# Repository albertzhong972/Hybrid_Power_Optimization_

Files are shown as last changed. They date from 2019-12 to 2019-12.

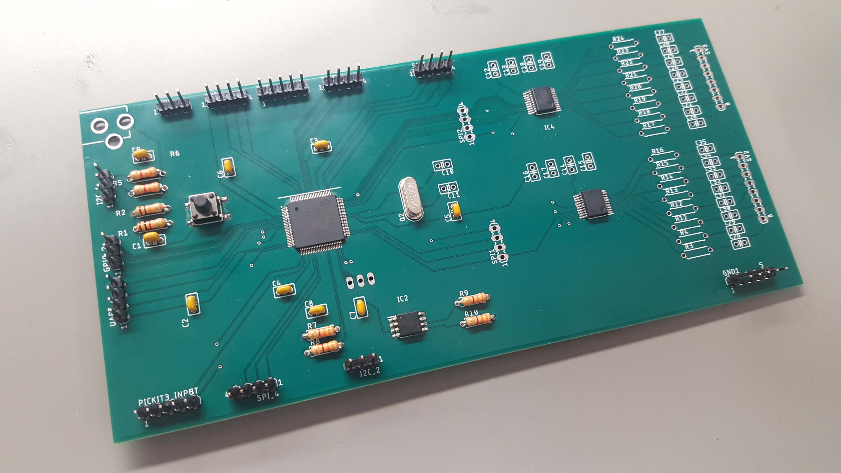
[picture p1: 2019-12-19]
Albert's Files/20191014_151341.jpg

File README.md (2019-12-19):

# Hybrid-Power-Optimization
ECEN 404 Senior Design - Hybrid Power Optimization

Project Description:
We are combining DC power from a solar panel with AC power from the grid to provide power to a load. We are using a PIC32MK microcontroller in this project.

There are four subsystems:
  -Power (Antonio)
  -PCB (Albert)
  -Software/Firmware (Eduardo)
  -Feedback (Heraclio)

  You can find our individual work as well as our progress reports in our own folders.

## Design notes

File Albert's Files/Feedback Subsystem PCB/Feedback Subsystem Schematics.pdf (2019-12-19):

AC Voltage Read Circuit
Schematic

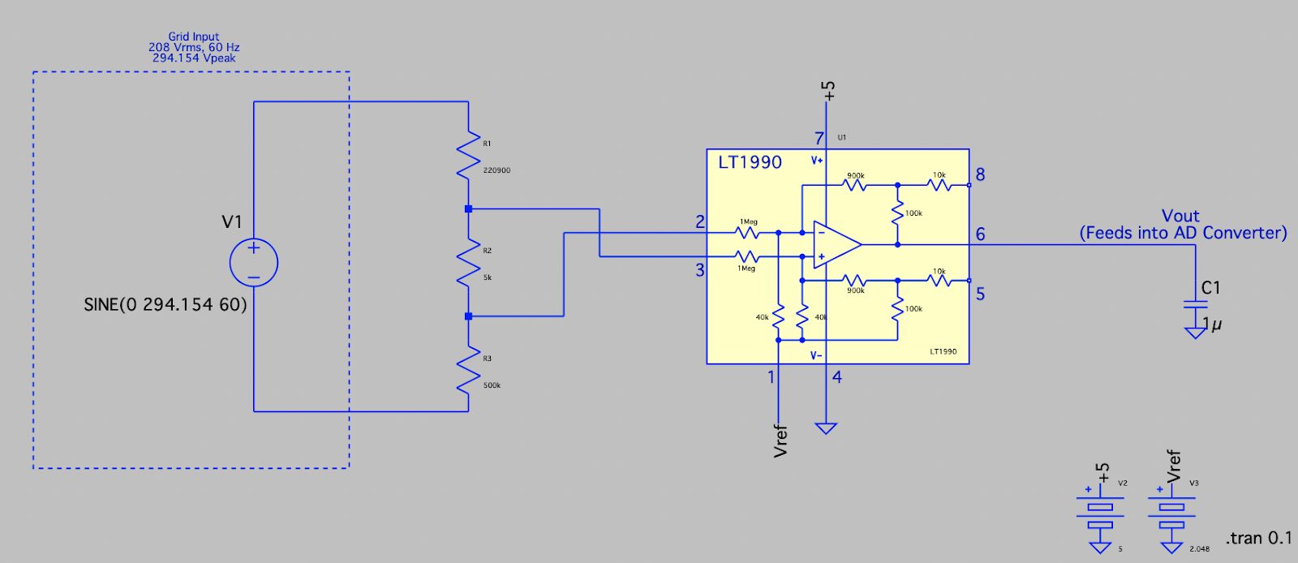
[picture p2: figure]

Link to LT1990 on DigiKey: https://bit.ly/2GjcjCH
Link to LT1990 DataSheet: https://bit.ly/2KG9r8o

*NOTE: All resistors are normal through hole resistors.

AC Current Read Circuit
Schematic

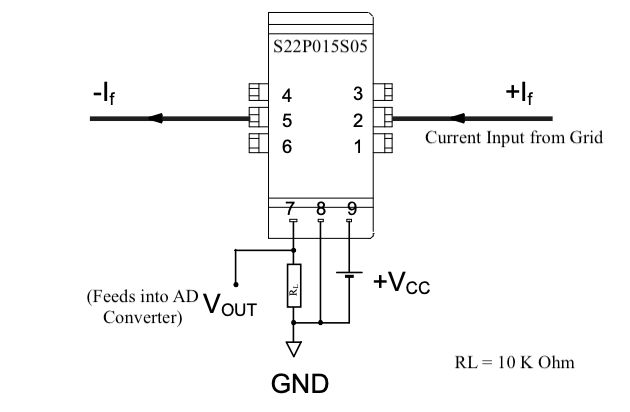
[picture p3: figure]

Link to S22P015S05 on DigiKey: https://bit.ly/2ZiuReU
Link to S22P015S05 DataSheet: https://bit.ly/2GquNCG

*NOTE: For this current read circuit I am missing a noise filter circuit that Dr. Lusher told me today to add. It should connect to Vout. I will be working on that and will send that part when complete.

Resistors here are also normal through hole resistors.

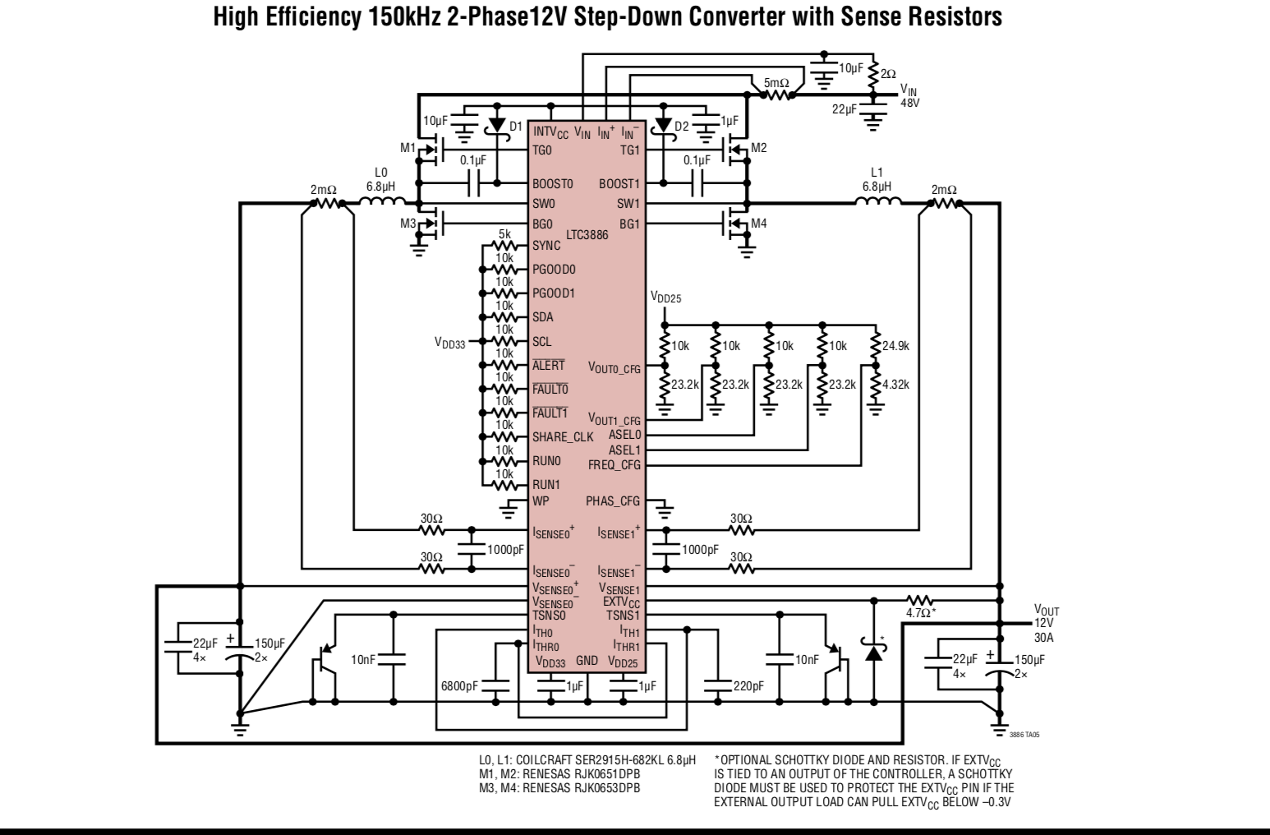
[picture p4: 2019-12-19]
Albert's Files/Power Subsystem PCB/Screen Shot 2019-04-16 at 8.33.40 AM.png

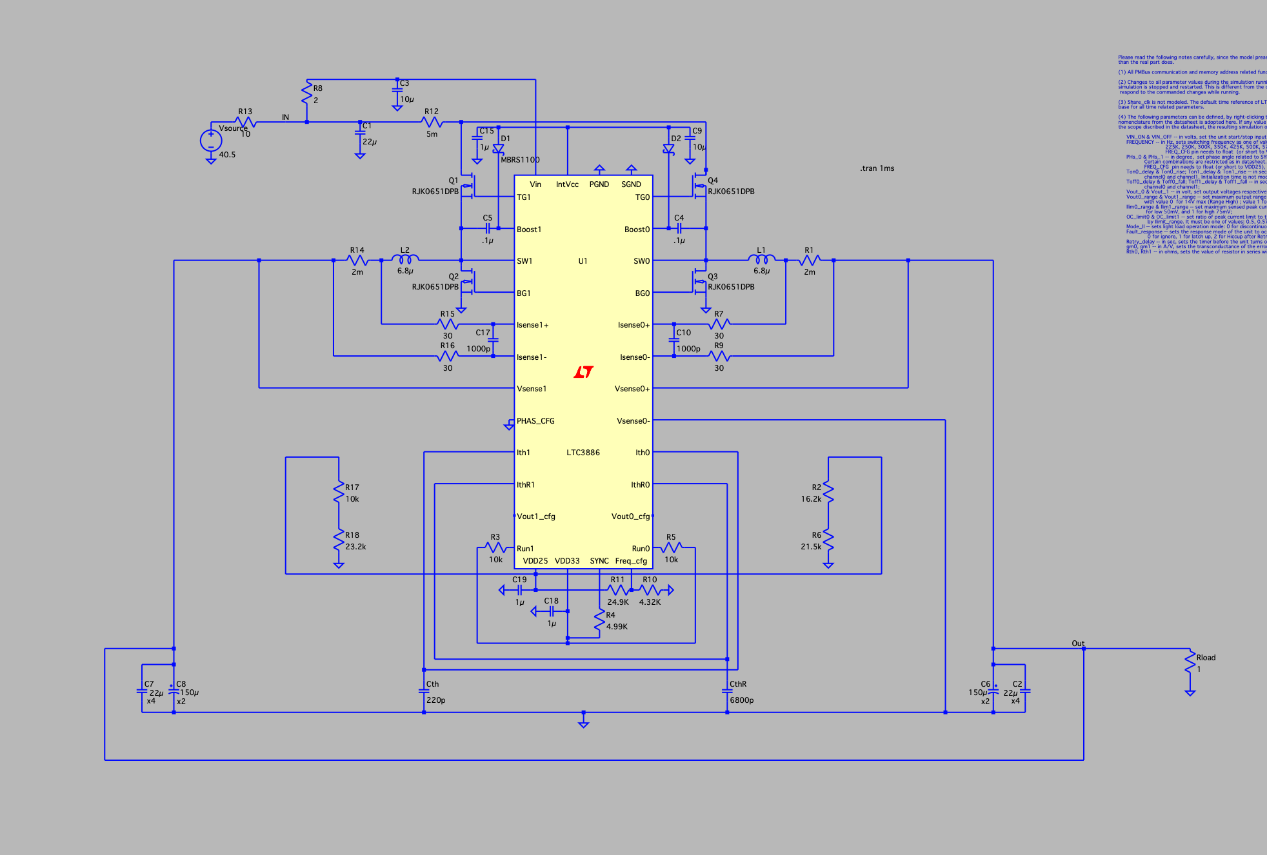
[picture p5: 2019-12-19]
Albert's Files/Power Subsystem PCB/Screen Shot 2019-04-16 at 8.29.42 AM.png

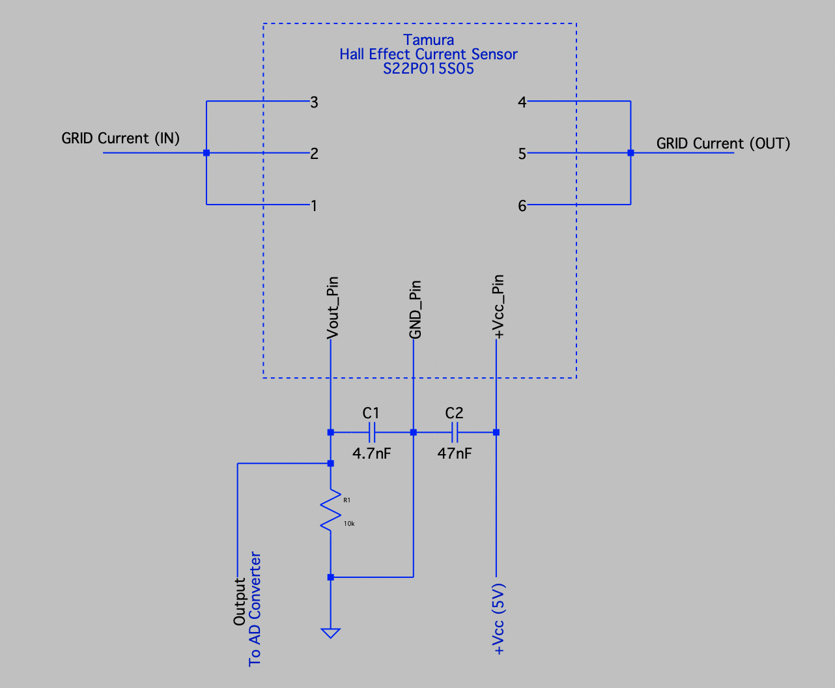
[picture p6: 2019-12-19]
Albert's Files/Feedback Subsystem PCB/temura sensor.png

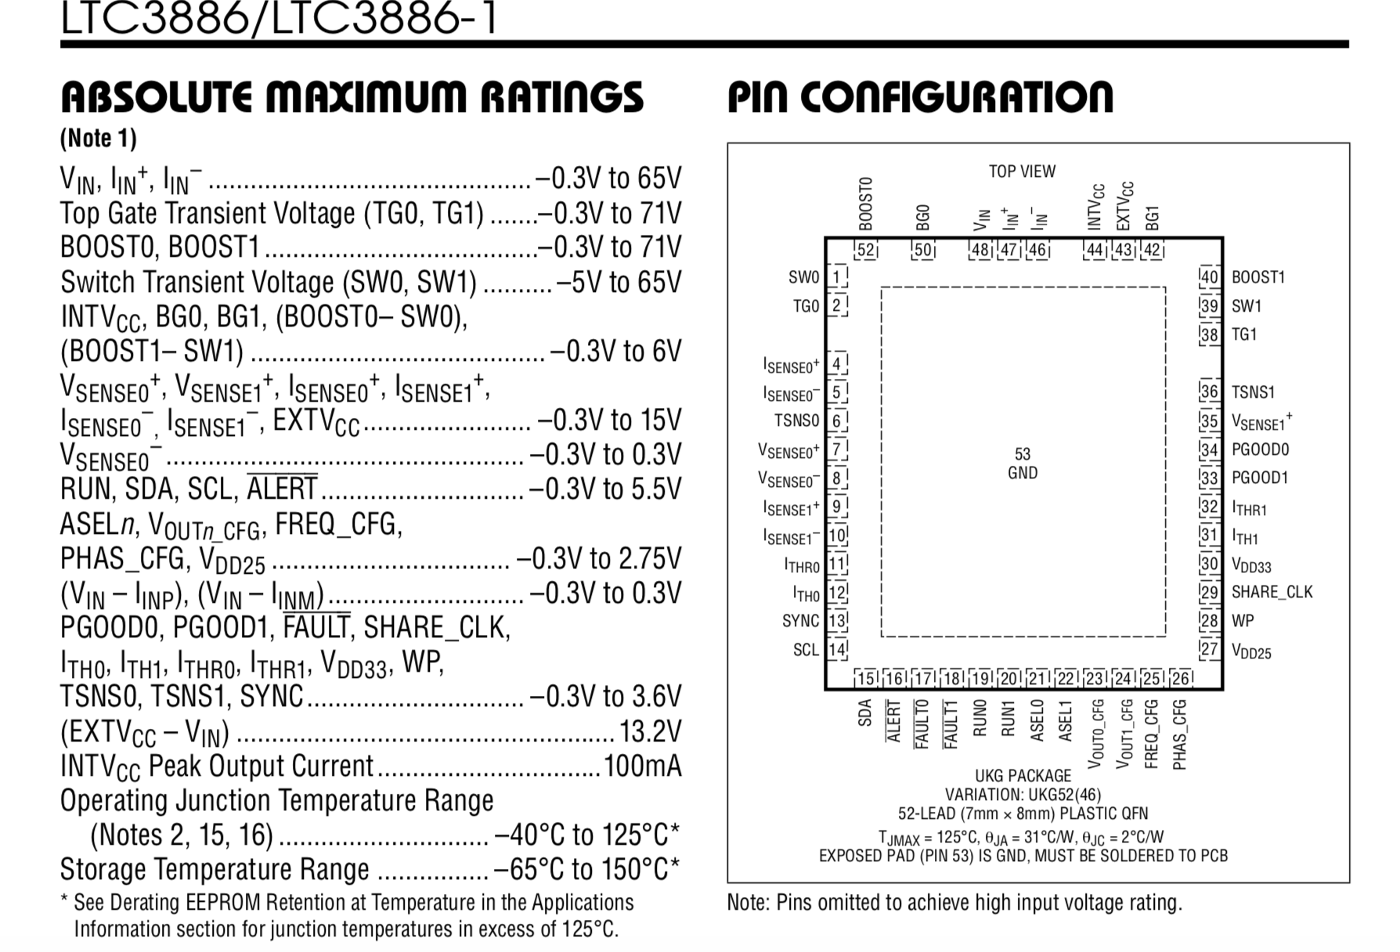
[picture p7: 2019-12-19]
Albert's Files/Power Subsystem PCB/Screen Shot 2019-04-16 at 8.33.58 AM.png

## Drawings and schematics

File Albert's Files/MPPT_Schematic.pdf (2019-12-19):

# C19 R¹⁰ R¹¹

# C18 R⁴

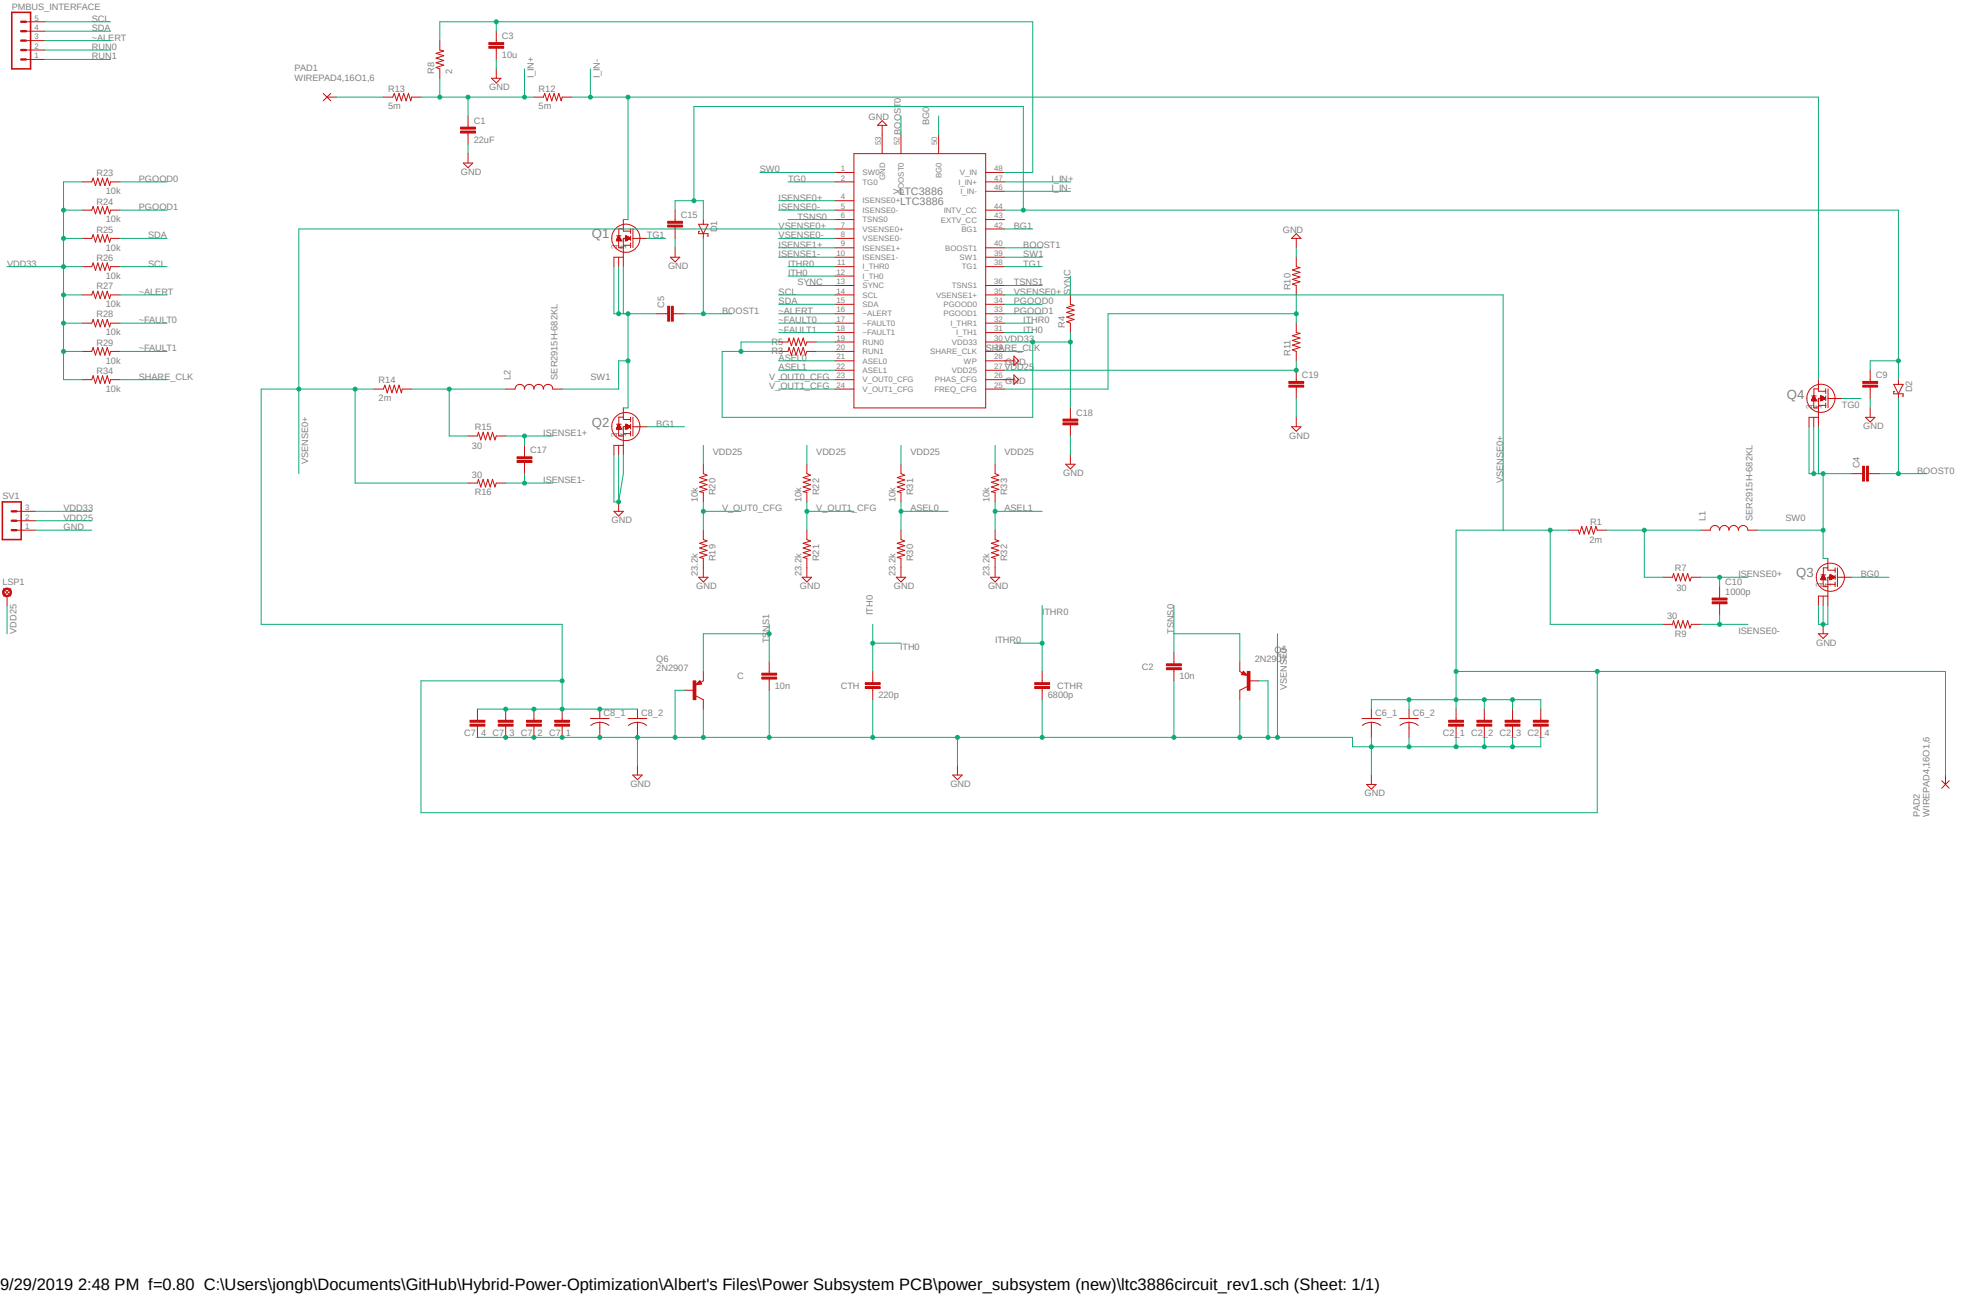
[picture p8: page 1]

9/29/2019 2:48 PM f=0.80 C:\Users\jongb\Documents\GitHub\Hybrid-Power-Optimization\Albert's Files\Power Subsystem PCB\power_subsystem (new)\ltc3886circuit_rev1.sch (Sheet: 1/1)

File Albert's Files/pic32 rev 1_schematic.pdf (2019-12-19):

# C6 C⁷

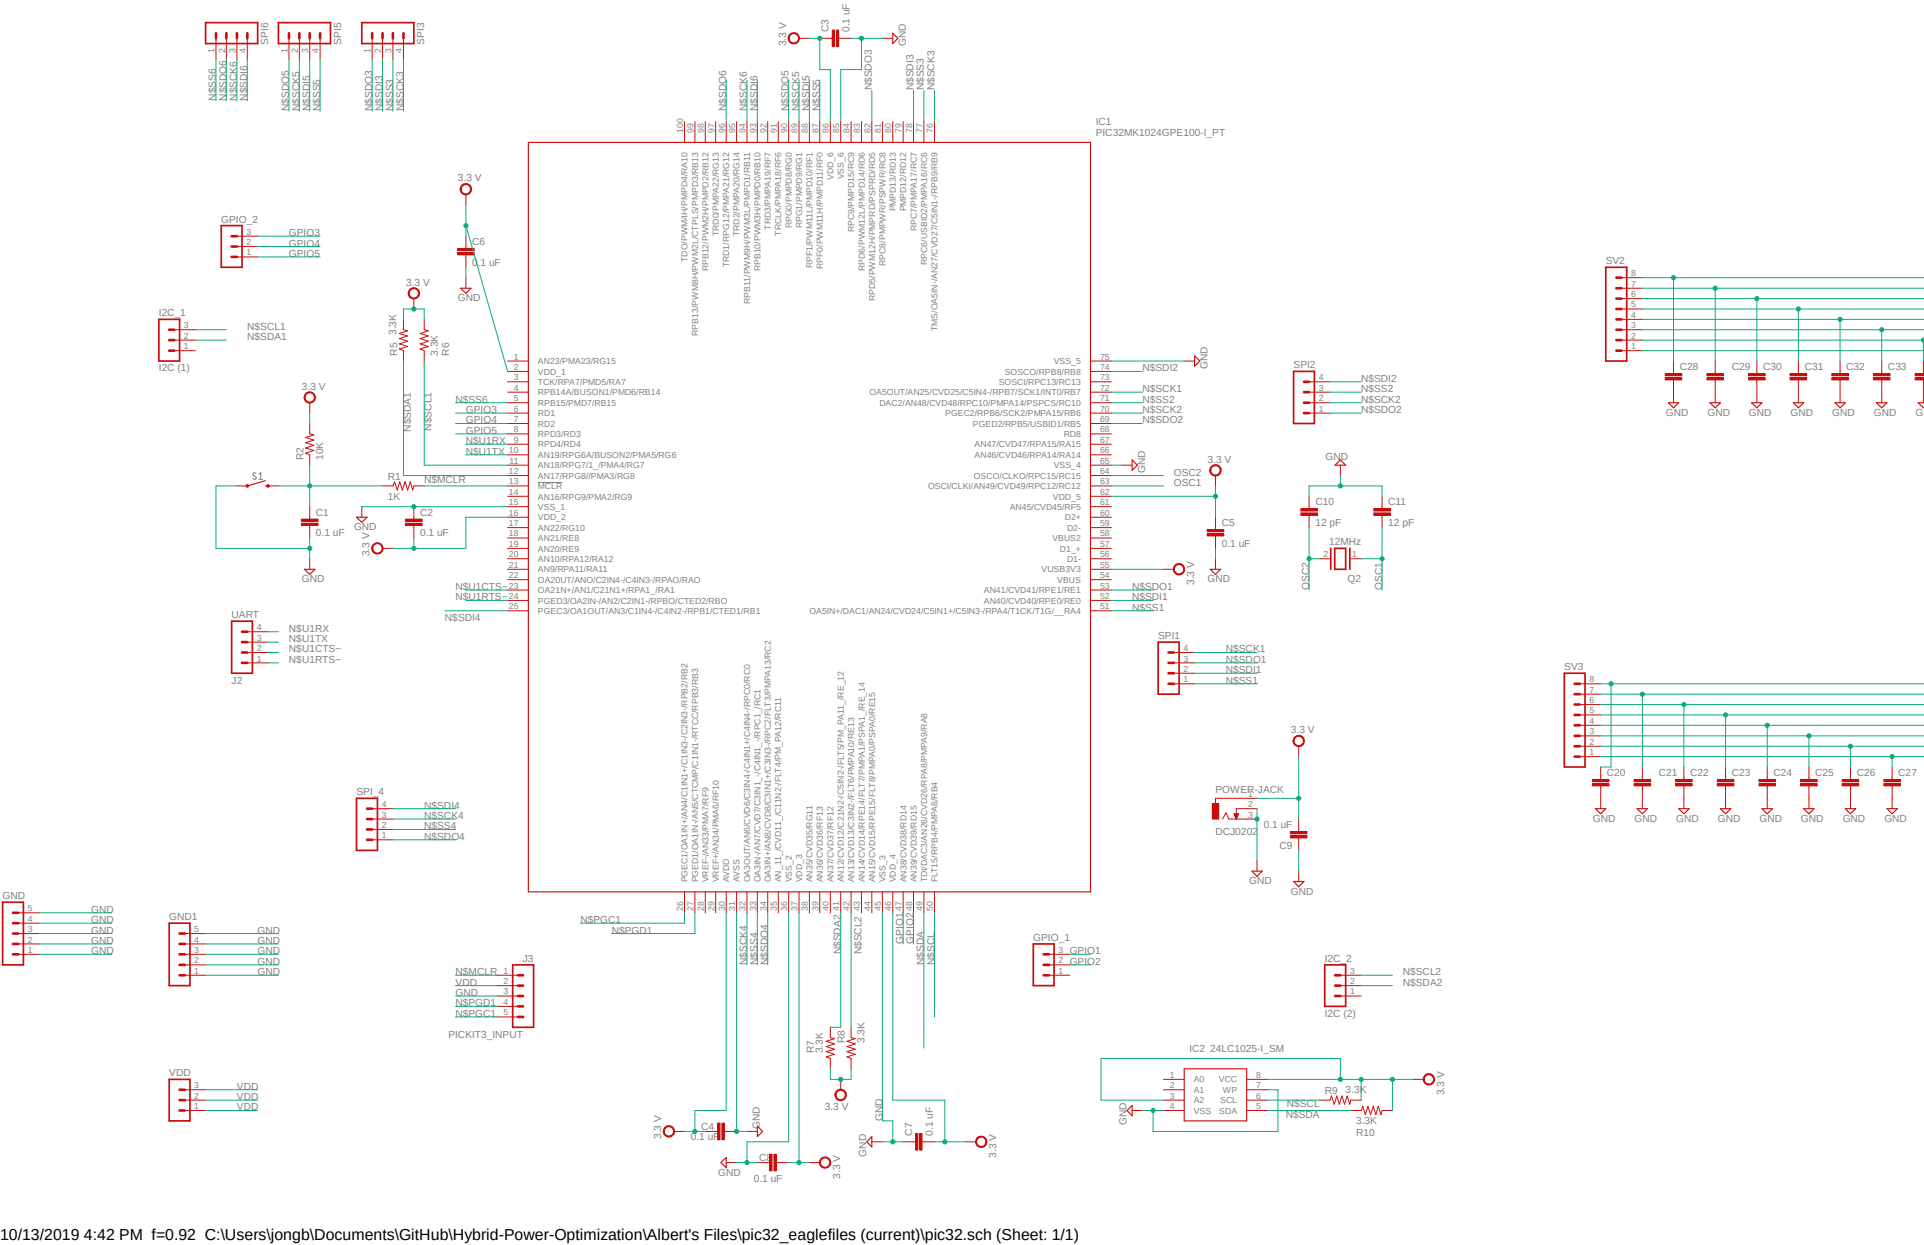
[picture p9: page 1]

10/13/2019 4:42 PM f=0.92 C:\Users\jongb\Documents\GitHub\Hybrid-Power-Optimization\Albert's Files\pic32_eaglefiles (current)\pic32.sch (Sheet: 1/1)

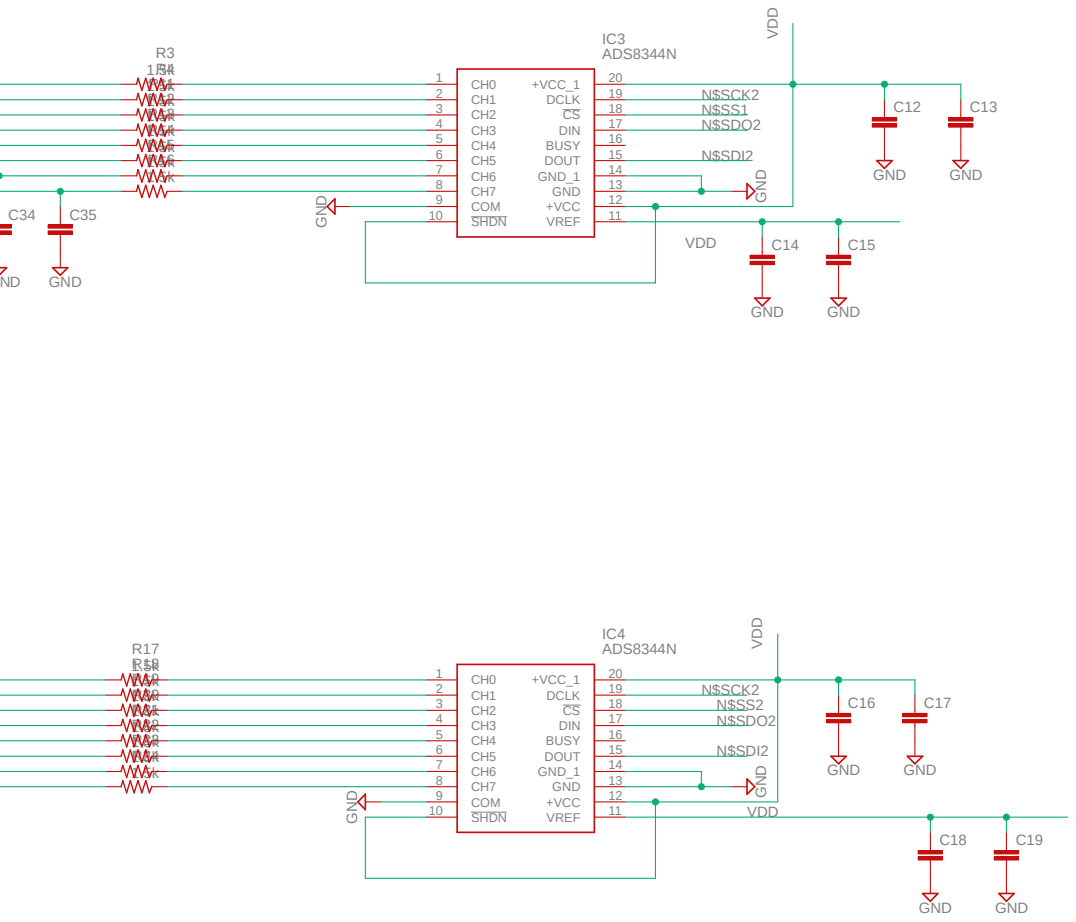
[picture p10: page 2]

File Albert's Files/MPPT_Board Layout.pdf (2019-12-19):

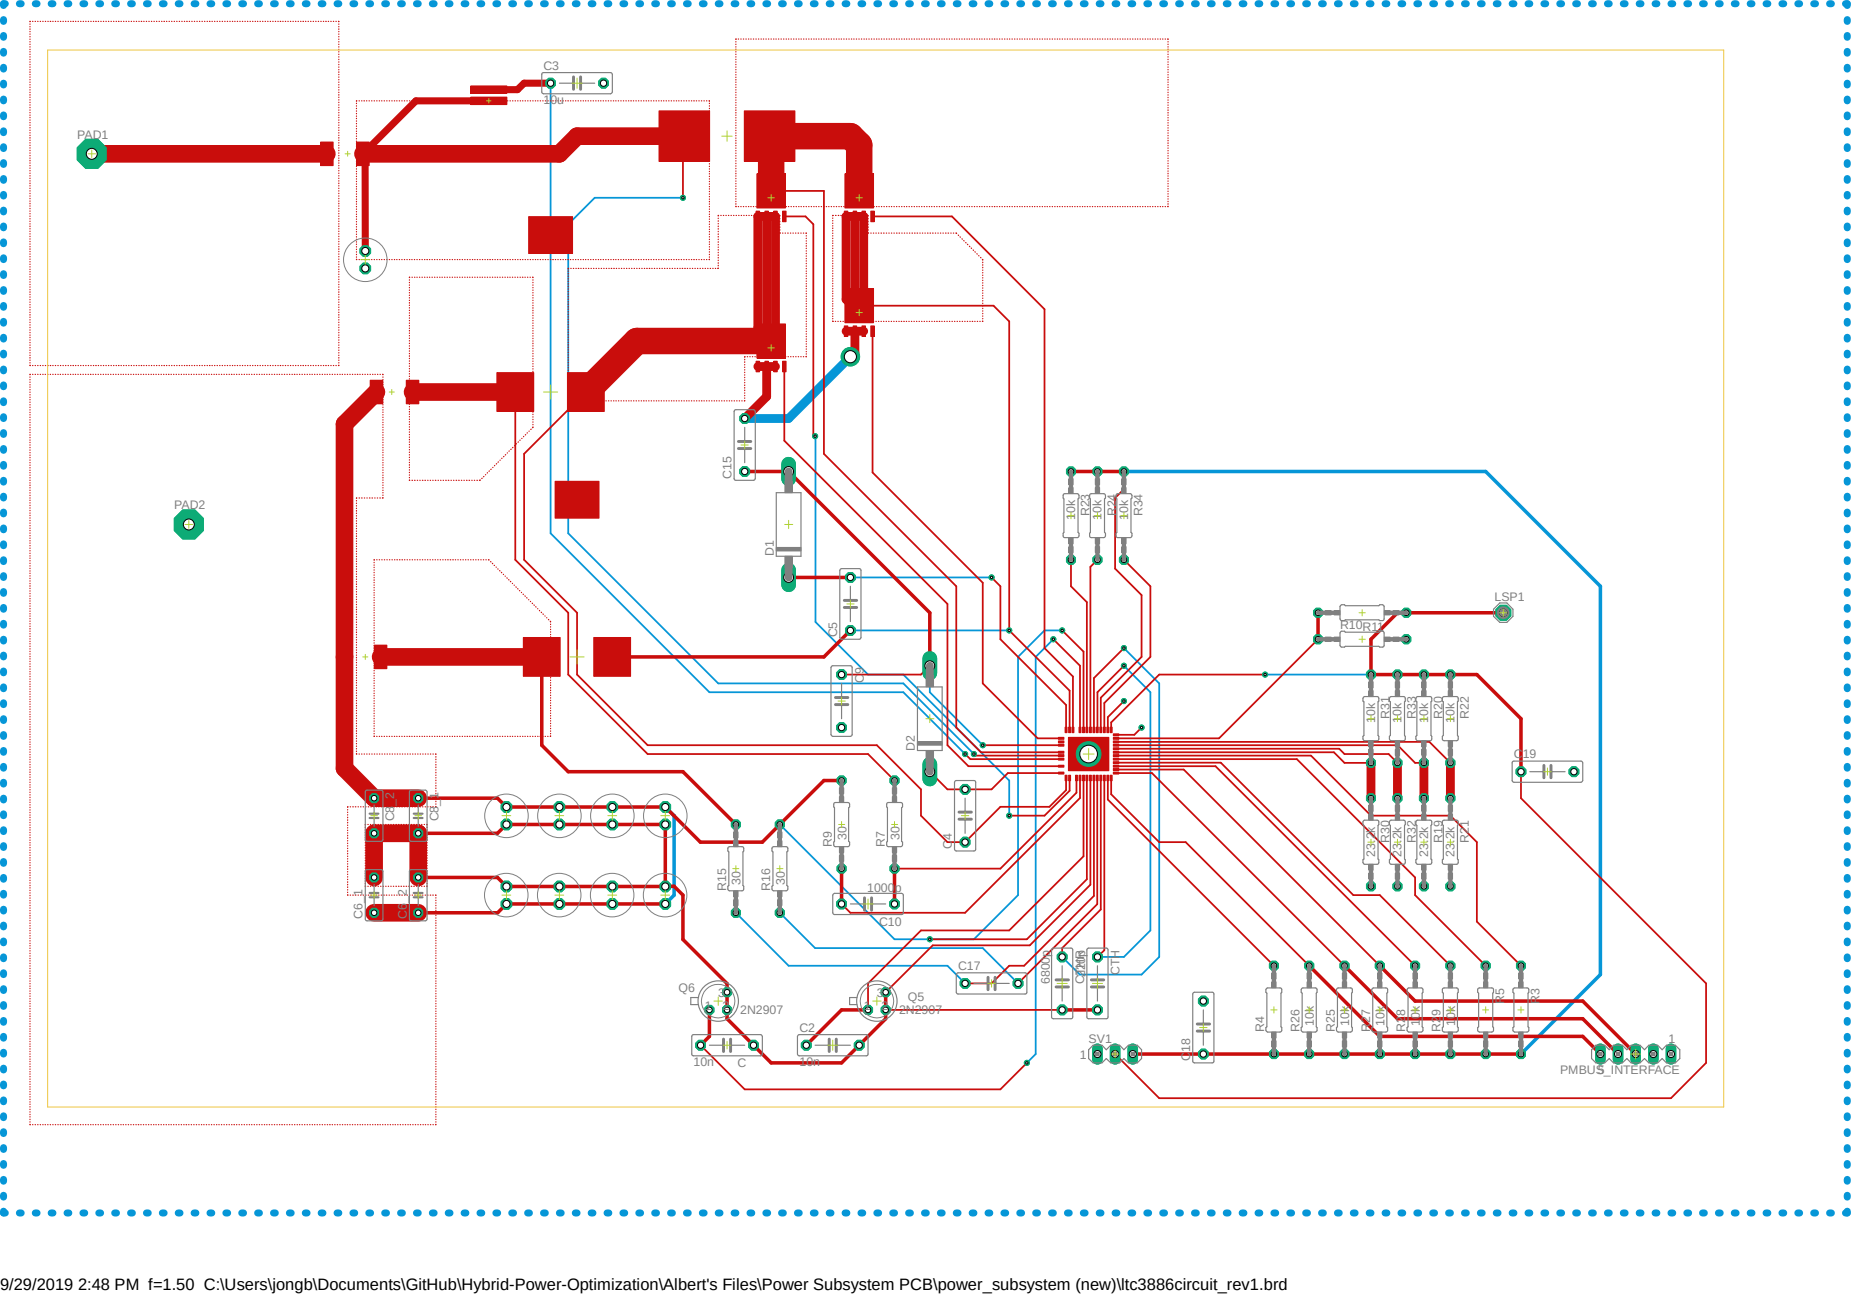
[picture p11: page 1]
C10 C¹⁵; C¹⁸; CTH CTHR; PAD1; PAD2; PMBUS_INTERFACE; R10R11 R¹⁵; R¹⁶; R¹⁹ R²⁰; R²¹ R²² R²³; R²⁴; R²⁶; R²⁵; R²⁷; R²⁸; R²⁹; R³ R³⁰ R³¹; R³² R³³ R³⁴; LSP1 D¹

9/29/2019 2:48 PM f=1.50 C:\Users\jongb\Documents\GitHub\Hybrid-Power-Optimization\Albert's Files\Power Subsystem PCB\power_subsystem (new)\ltc3886circuit_rev1.brd

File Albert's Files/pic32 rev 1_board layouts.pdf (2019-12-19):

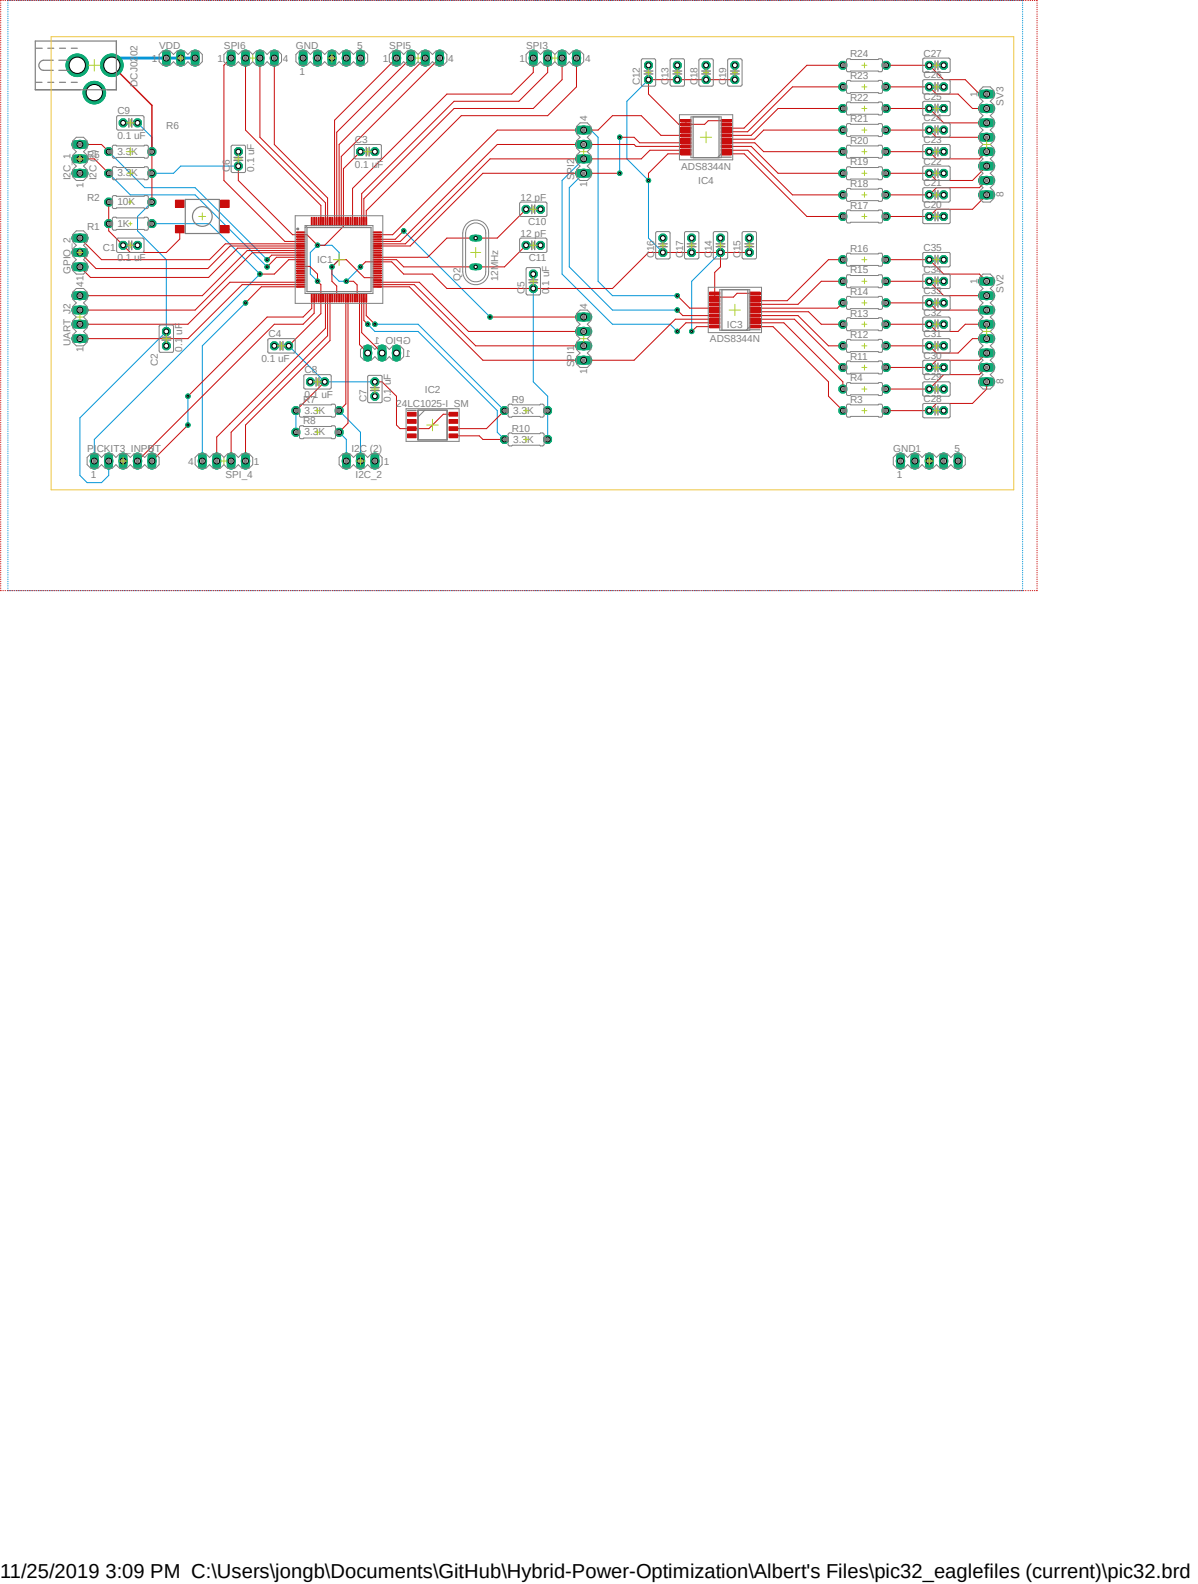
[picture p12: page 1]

11/25/2019 3:09 PM C:\Users\jongb\Documents\GitHub\Hybrid-Power-Optimization\Albert's Files\pic32_eaglefiles (current)\pic32.brd

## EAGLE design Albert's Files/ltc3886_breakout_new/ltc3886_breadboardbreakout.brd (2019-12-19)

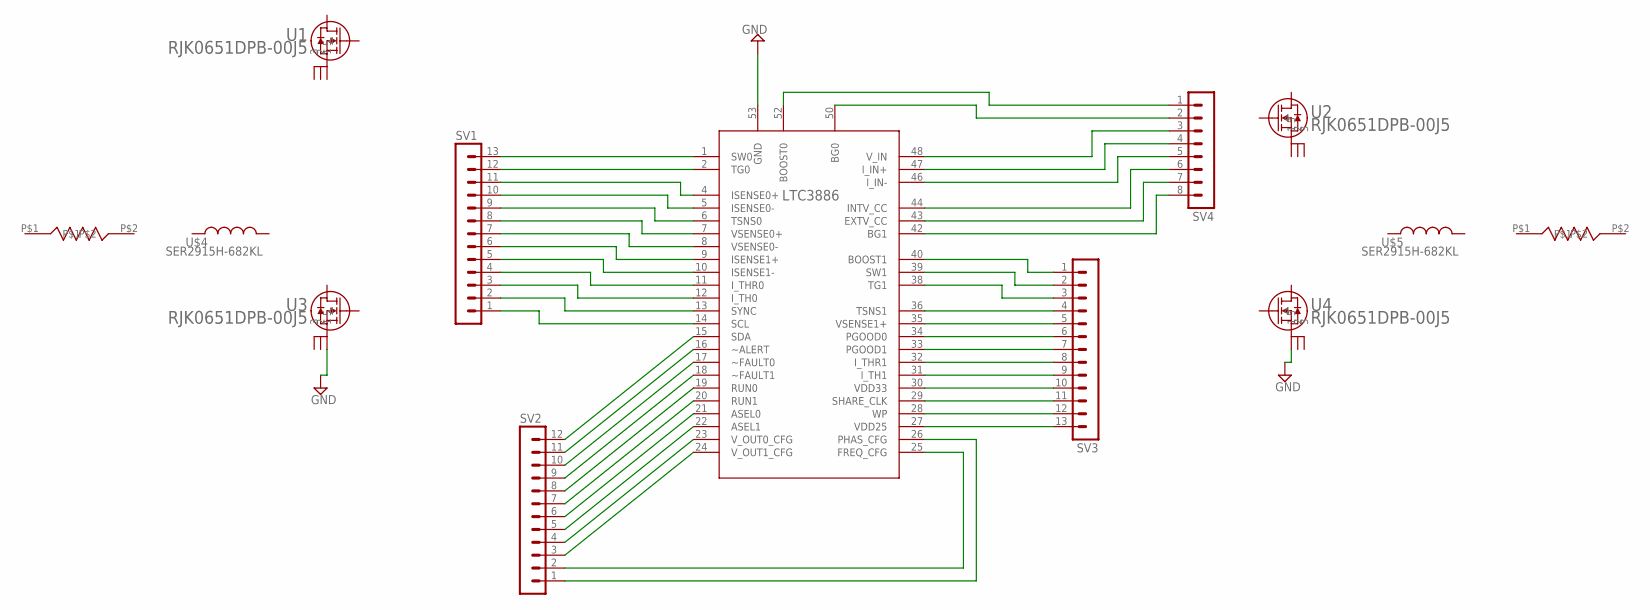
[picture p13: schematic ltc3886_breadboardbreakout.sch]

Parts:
GND: LTC3886; QFN-52_UKG_2
SV1, SV3: MA13-1
SV2: MA12-1
SV4: MA08-1
U1, U2, U3, U4: RJK0651DPB-00J5; LFPAK
U$2, U$3: CSS2H-2512K-2L00FE
U$4, U$5: SER2915H-682KL

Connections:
GND: GND.53 (GND), U3.1, U4.1
unnamed: GND.1 (SW0), SV1.13
unnamed: GND.2 (TG0), SV1.12
unnamed: GND.4 (ISENSE0+), SV1.11
unnamed: GND.5 (ISENSE0-), SV1.10
unnamed: GND.6 (TSNS0), SV1.9
unnamed: GND.7 (VSENSE0+), SV1.8
unnamed: GND.8 (VSENSE0-), SV1.7
unnamed: GND.9 (ISENSE1+), SV1.6
unnamed: GND.10 (ISENSE1-), SV1.5
unnamed: GND.11 (I_THR0), SV1.4
unnamed: GND.12 (I_TH0), SV1.3
unnamed: GND.13 (SYNC), SV1.2
unnamed: GND.14 (SCL), SV1.1
unnamed: GND.24 (V_OUT1_CFG), SV2.3
unnamed: GND.23 (V_OUT0_CFG), SV2.4
unnamed: GND.22 (ASEL1), SV2.5
unnamed: GND.21 (ASEL0), SV2.6
unnamed: GND.20 (RUN1), SV2.7
unnamed: GND.19 (RUN0), SV2.8
unnamed: GND.18 (~FAULT1), SV2.9
unnamed: GND.17 (~FAULT0), SV2.10
unnamed: GND.16 (~ALERT), SV2.11
unnamed: GND.15 (SDA), SV2.12
unnamed: GND.25 (FREQ_CFG), SV2.2
unnamed: GND.26 (PHAS_CFG), SV2.1
unnamed: GND.27 (VDD25), SV3.13
unnamed: GND.28 (WP), SV3.12
unnamed: GND.29 (SHARE_CLK), SV3.11
unnamed: GND.30 (VDD33), SV3.10
unnamed: GND.31 (I_TH1), SV3.9
unnamed: GND.32 (I_THR1), SV3.8
unnamed: GND.33 (PGOOD1), SV3.7
unnamed: GND.34 (PGOOD0), SV3.6
unnamed: GND.35 (VSENSE1+), SV3.5
unnamed: GND.36 (TSNS1), SV3.4
unnamed: GND.38 (TG1), SV3.3
unnamed: GND.39 (SW1), SV3.2
unnamed: GND.40 (BOOST1), SV3.1
unnamed: GND.42 (BG1), SV4.8
unnamed: GND.43 (EXTV_CC), SV4.7
unnamed: GND.44 (INTV_CC), SV4.6
unnamed: GND.46 (I_IN-), SV4.5
unnamed: GND.47 (I_IN+), SV4.4
unnamed: GND.48 (V_IN), SV4.3
unnamed: GND.50 (BG0), SV4.2
unnamed: GND.52 (BOOST0), SV4.1

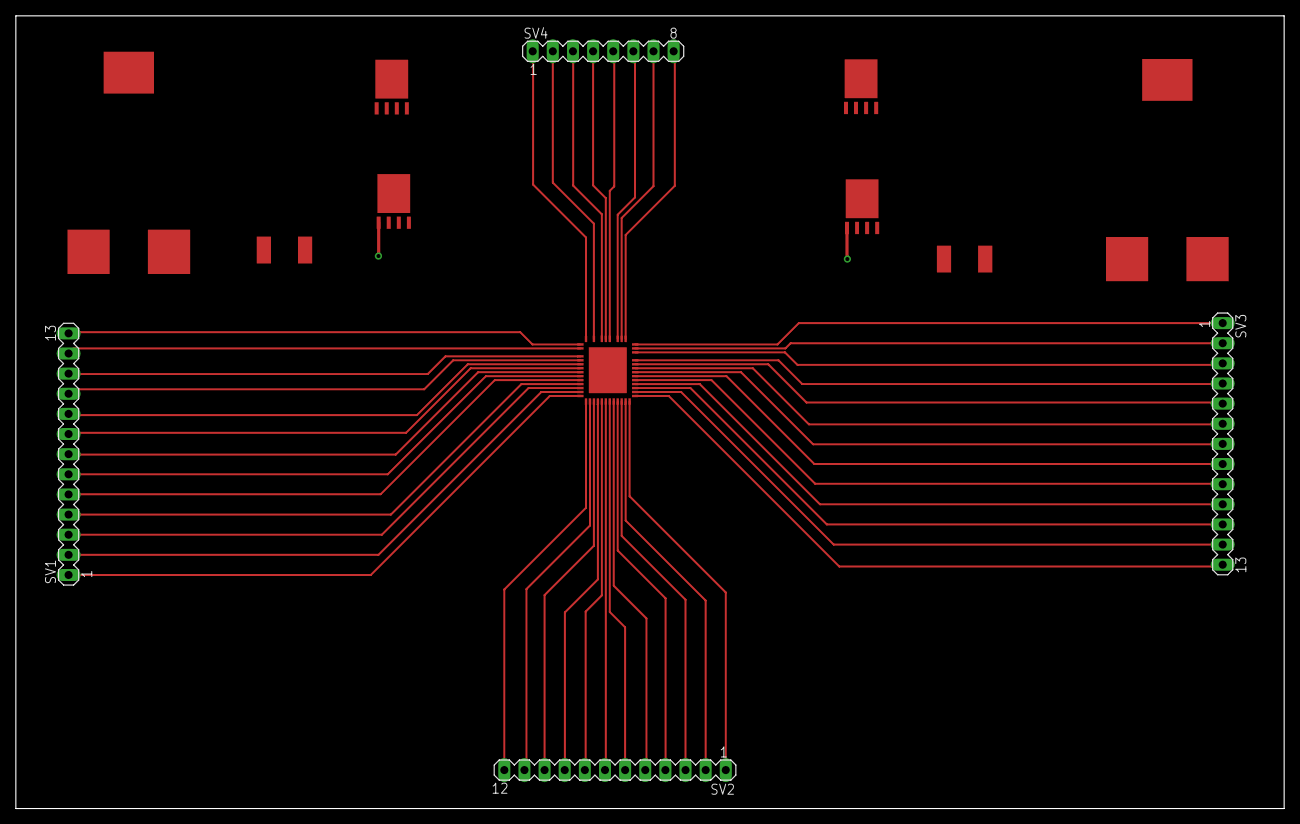
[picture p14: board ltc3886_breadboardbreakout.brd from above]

Board: 2 copper layers, 160.0 x 100.0 mm, 13 parts (0 on the bottom side), 47 nets.

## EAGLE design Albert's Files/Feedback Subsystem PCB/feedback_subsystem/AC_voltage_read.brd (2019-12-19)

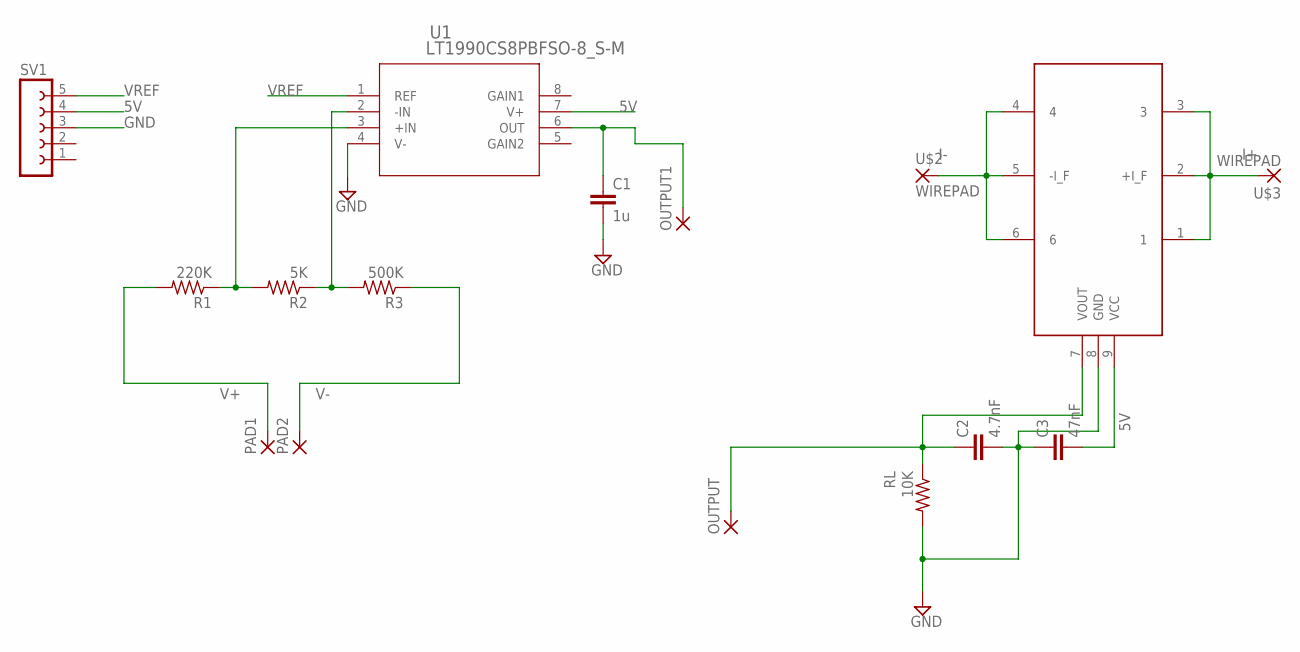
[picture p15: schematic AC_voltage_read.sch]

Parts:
C1: 1u; C075-032X103
C2: 4.7nF; C050-045X075
C3: 47nF; C050-045X075
OUTPUT, OUTPUT1: WIREPAD3,17/1,2; 3,17/1,2
PAD1, PAD2: 3,81/1,1
R1: 220K; 0207/12
R2: 5K; 0207/12
R3: 500K; 0207/12
RL: 10K; 0207/12
SV1: FE05-1
U1: LT1990CS8PBFSO-8_S-M; SO-8_S-M
U$1: S22P015S05; S22FOOTPRINT
U$2, U$3: WIREPAD

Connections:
5V: C3.2, SV1.4, U1.7 (V+), U$1.9 (VCC)
GND: C1.2, C2.2, C3.1, RL.2, SV1.3, U1.4 (V-), U$1.8 (GND)
I+: U$1.1, U$1.2 (+I_F), U$1.3, U$3.P$1
I-: U$1.4, U$1.5 (-I_F), U$1.6, U$2.P$1
unnamed: R2.1, R3.2, U1.2 (-IN)
unnamed: C1.1, OUTPUT1.1, U1.6 (OUT)
unnamed: C2.1, OUTPUT.1, RL.1, U$1.7 (VOUT)
unnamed: R1.1, R2.2, U1.3 (+IN)
V+: PAD1.1, R1.2
V-: PAD2.1, R3.1
VREF: SV1.5, U1.1 (REF)

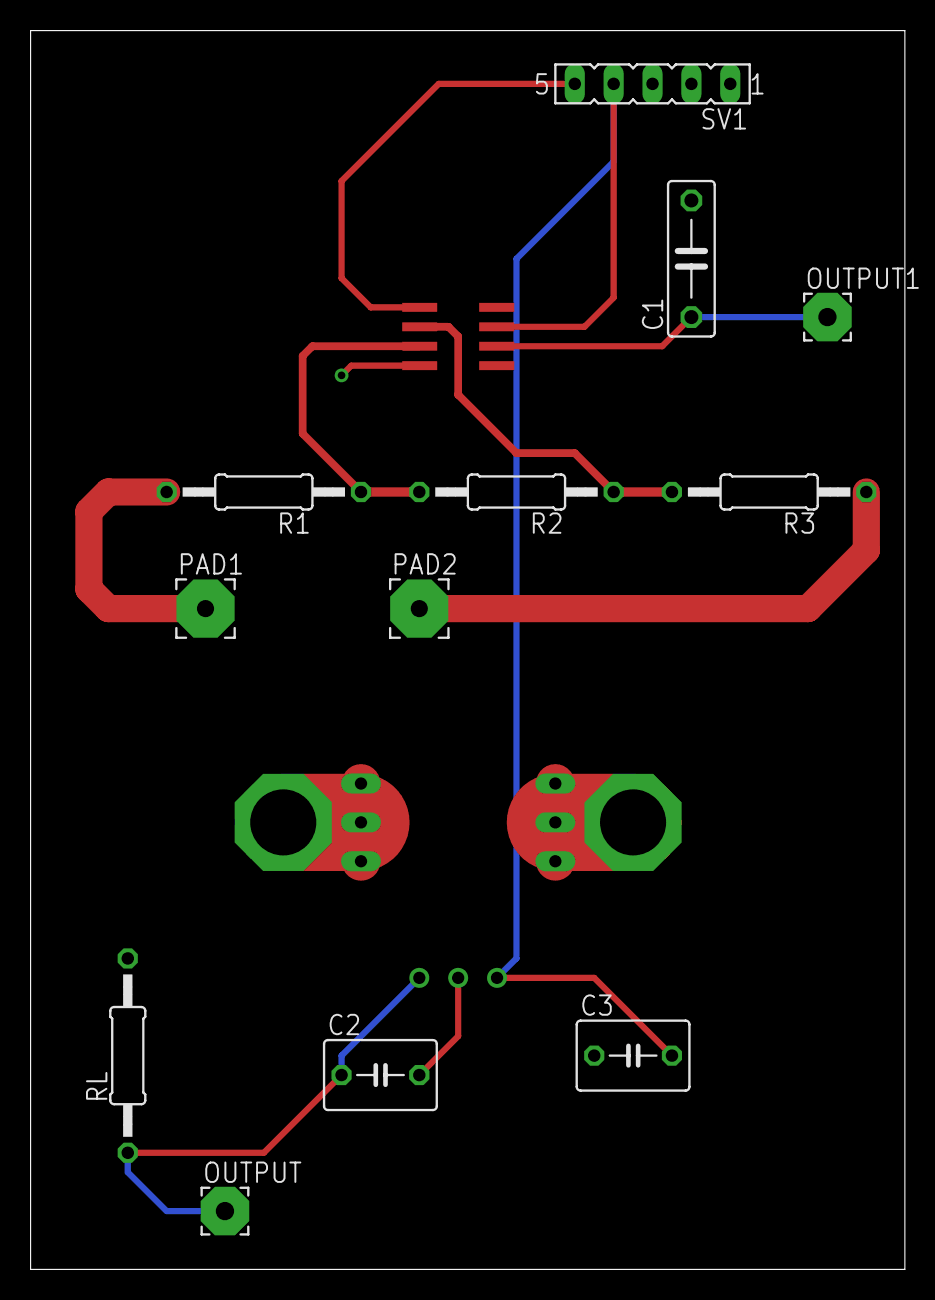
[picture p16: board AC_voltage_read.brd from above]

Board: 2 copper layers, 57.1 x 80.9 mm, 16 parts (0 on the bottom side), 11 nets.

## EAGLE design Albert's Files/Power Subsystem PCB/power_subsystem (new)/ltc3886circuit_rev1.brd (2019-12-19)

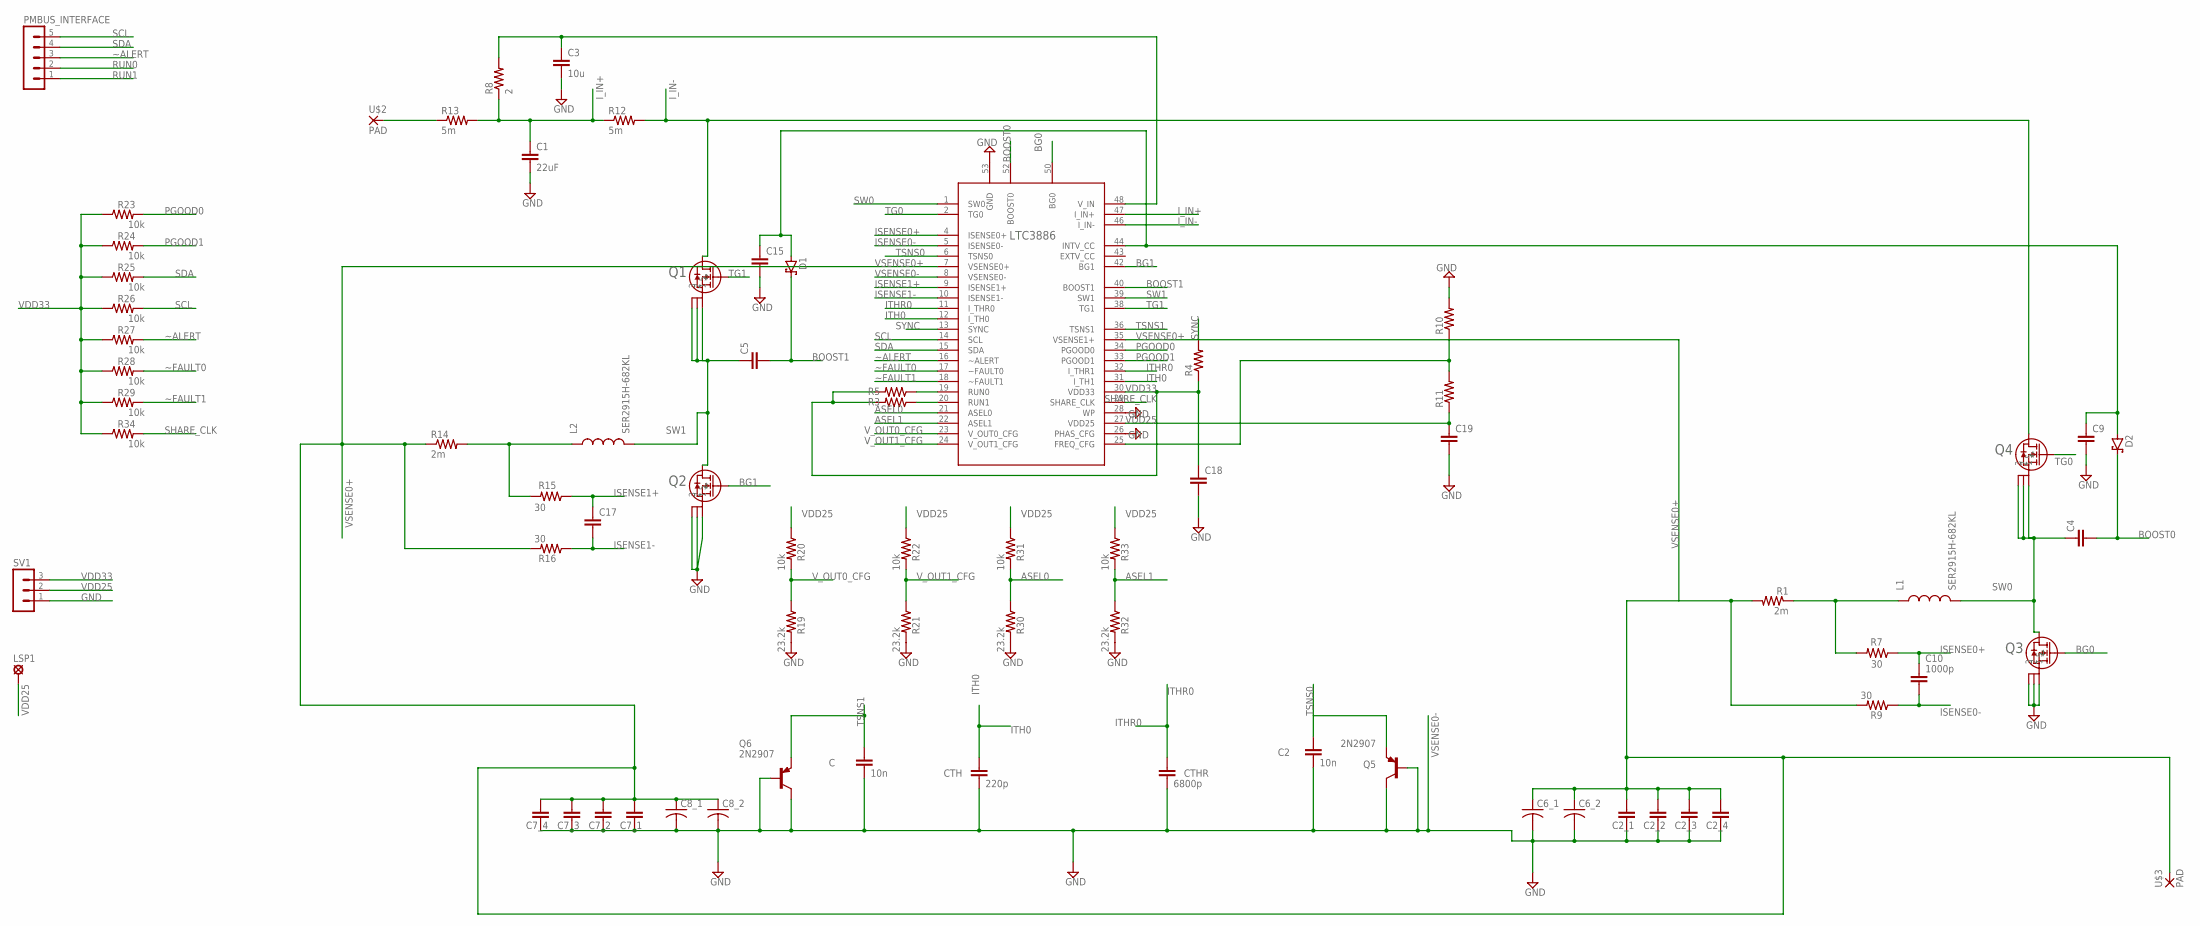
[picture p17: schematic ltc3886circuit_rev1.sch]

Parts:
C, C2: 10n; C075-032X103
C1: 22uF; ESK226M100AE3AA(22UF_CAP)
C2_1, C2_2, C2_3, C2_4, C7_1, C7_2, C7_3, C7_4: ESK226M100AE3AA(22UF_CAP)
C3: 10u; C075-032X103
C4, C5, C9, C15, C17, C18, C19: C-EU075-032X103; C075-032X103
C6_1, C6_2, C8_1, C8_2: C-US050-025X075; C050-025X075
C10: 1000p; C075-032X103
CTH: 220p; C075-032X103
CTHR: 6800p; C075-032X103
D1, D2: SCHOTTKY-DIODECB417-15; CB417-15
L1, L2: SER2915H-682KL
LSP1: MCS08
PMBUS_INTERFACE: MA05-1
Q1, Q2, Q3, Q4: RJK0651DPB-00J5; LFPAK
Q5, Q6: 2N2907; TO18
R1, R14: 2m; CSS2H-2512K-2L00FE
R3, R4, R5, R10, R11: R-US_0207/12; 0207/12
R7, R9, R15, R16: 30; 0207/12
R8: 2; ERJ-B1BF2R0U(2-OHM)
R12: 5m; CSS4J-4026K-5L00F(5M-OHM)
R13: 5m; CSS2H-2512K-2L00FE
R19, R21, R30, R32: 23.2k; 0207/12
R20, R22, R23, R24, R25, R26, R27, R28, R29, R31, R33, R34: 10k; 0207/12
SV1: MA03-1
U$1: LTC3886; QFN-52_UKG_2
U$2, U$3: PAD

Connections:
ASEL0: R30.1, R31.2, U$1.21 (ASEL0)
ASEL1: R32.1, R33.2, U$1.22 (ASEL1)
BG0: Q3.4, U$1.50 (BG0)
BG1: Q2.4, U$1.42 (BG1)
BOOST0: C4.2, D2.C, U$1.52 (BOOST0)
BOOST1: C5.2, D1.C, U$1.40 (BOOST1)
GND: C1.P$2 (2), C3.2, C9.2, C15.2, C18.2, C19.2, Q2.1, Q2.2, Q2.3, Q3.1, Q3.2, Q3.3, R10.2, R19.2, R21.2, R30.2, R32.2, SV1.1, U$1.26 (PHAS_CFG), U$1.28 (WP), U$1.53 (GND)
ISENSE0+: C10.1, R7.1, U$1.4 (ISENSE0+)
ISENSE0-: C10.2, R9.1, U$1.5 (ISENSE0-)
ISENSE1+: C17.1, R15.1, U$1.9 (ISENSE1+)
ISENSE1-: C17.2, R16.1, U$1.10 (ISENSE1-)
ITH0: CTH.1, U$1.12 (I_TH0), U$1.31 (I_TH1)
ITHR0: CTHR.1, U$1.11 (I_THR0), U$1.32 (I_THR1)
I_IN+: C1.P$1 (1), R8.P$1 (1), R12.P$1 (1), R13.P$2 (2), U$1.47 (I_IN+)
I_IN-: Q1.5, Q4.5, R12.P$2 (2), U$1.46 (I_IN-)
unnamed: R5.1, U$1.19 (RUN0)
unnamed: R3.1, U$1.20 (RUN1)
unnamed: L2.P$1 (1), R14.P$2 (2), R15.2
unnamed: C9.1, C15.1, D1.A, D2.A, U$1.44 (INTV_CC)
unnamed: L1.P$1 (1), R1.P$1 (1), R7.2
unnamed: R13.P$1 (1), U$2.P$1
unnamed: C3.1, R8.P$2 (2), U$1.48 (V_IN)
unnamed: R10.1, R11.2, U$1.25 (FREQ_CFG)
PGOOD0: R23.2, U$1.34 (PGOOD0)
PGOOD1: R24.2, U$1.33 (PGOOD1)
RUN0: PMBUS_INTERFACE.2
RUN1: PMBUS_INTERFACE.1
SCL: PMBUS_INTERFACE.5, R26.2, U$1.14 (SCL)
SDA: PMBUS_INTERFACE.4, R25.2, U$1.15 (SDA)
SHARE_CLK: R34.2, U$1.29 (SHARE_CLK)
SW0: C4.1, L1.P$2 (2), Q3.5, Q4.1, Q4.2, Q4.3, U$1.1 (SW0)
SW1: C5.1, L2.P$2 (2), Q1.1, Q1.2, Q1.3, Q2.5, U$1.39 (SW1)
SYNC: R4.2, U$1.13 (SYNC)
TG0: Q4.4, U$1.2 (TG0)
TG1: Q1.4, U$1.38 (TG1)
TSNS0: C2.1, Q5.1 (E), U$1.6 (TSNS0)
TSNS1: C.1, Q6.1 (E), U$1.36 (TSNS1)
VDD25: C19.1, LSP1.MP, R11.1, R20.1, R22.1, R31.1, R33.1, SV1.2, U$1.27 (VDD25)
VDD33: C18.1, R3.2, R4.1, R5.2, R23.1, R24.1, R25.1, R26.1, R27.1, R28.1, R29.1, R34.1, SV1.3, U$1.30 (VDD33)
VSENSE0+: C2_1.P$1 (1), C2_2.P$1 (1), C2_3.P$1 (1), C2_4.P$1 (1), C6_1.1, C6_2.1, C7_1.P$1 (1), C7_2.P$1 (1), C7_3.P$1 (1), C7_4.P$1 (1), C8_1.1, C8_2.1, R1.P$2 (2), R9.2, R14.P$1 (1), R16.2, U$1.7 (VSENSE0+), U$1.35 (VSENSE1+), U$3.P$1
VSENSE0-: C.2, C2.2, C2_1.P$2 (2), C2_2.P$2 (2), C2_3.P$2 (2), C2_4.P$2 (2), C6_1.2, C6_2.2, C7_1.P$2 (2), C7_2.P$2 (2), C7_3.P$2 (2), C7_4.P$2 (2), C8_1.2, C8_2.2, CTH.2, CTHR.2, Q5.2 (B), Q5.3 (C), Q6.2 (B), Q6.3 (C), U$1.8 (VSENSE0-)
V_OUT0_CFG: R19.1, R20.2, U$1.23 (V_OUT0_CFG)
V_OUT1_CFG: R21.1, R22.2, U$1.24 (V_OUT1_CFG)
~ALERT: PMBUS_INTERFACE.3, R27.2, U$1.16 (~ALERT)
~FAULT0: R28.2, U$1.17 (~FAULT0)
~FAULT1: R29.2, U$1.18 (~FAULT1)

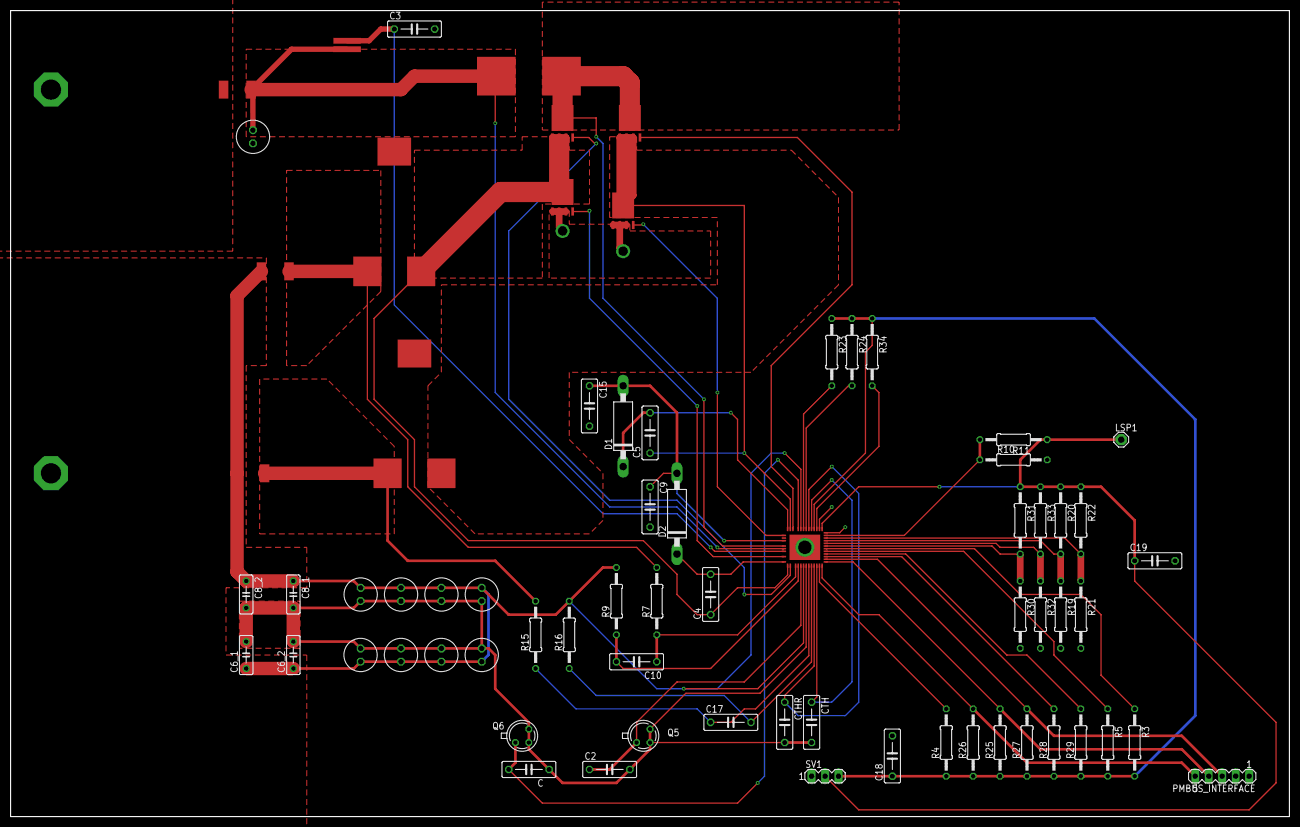
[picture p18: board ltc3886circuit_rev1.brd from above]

Board: 2 copper layers, 241.3 x 152.1 mm, 72 parts (0 on the bottom side), 44 nets.

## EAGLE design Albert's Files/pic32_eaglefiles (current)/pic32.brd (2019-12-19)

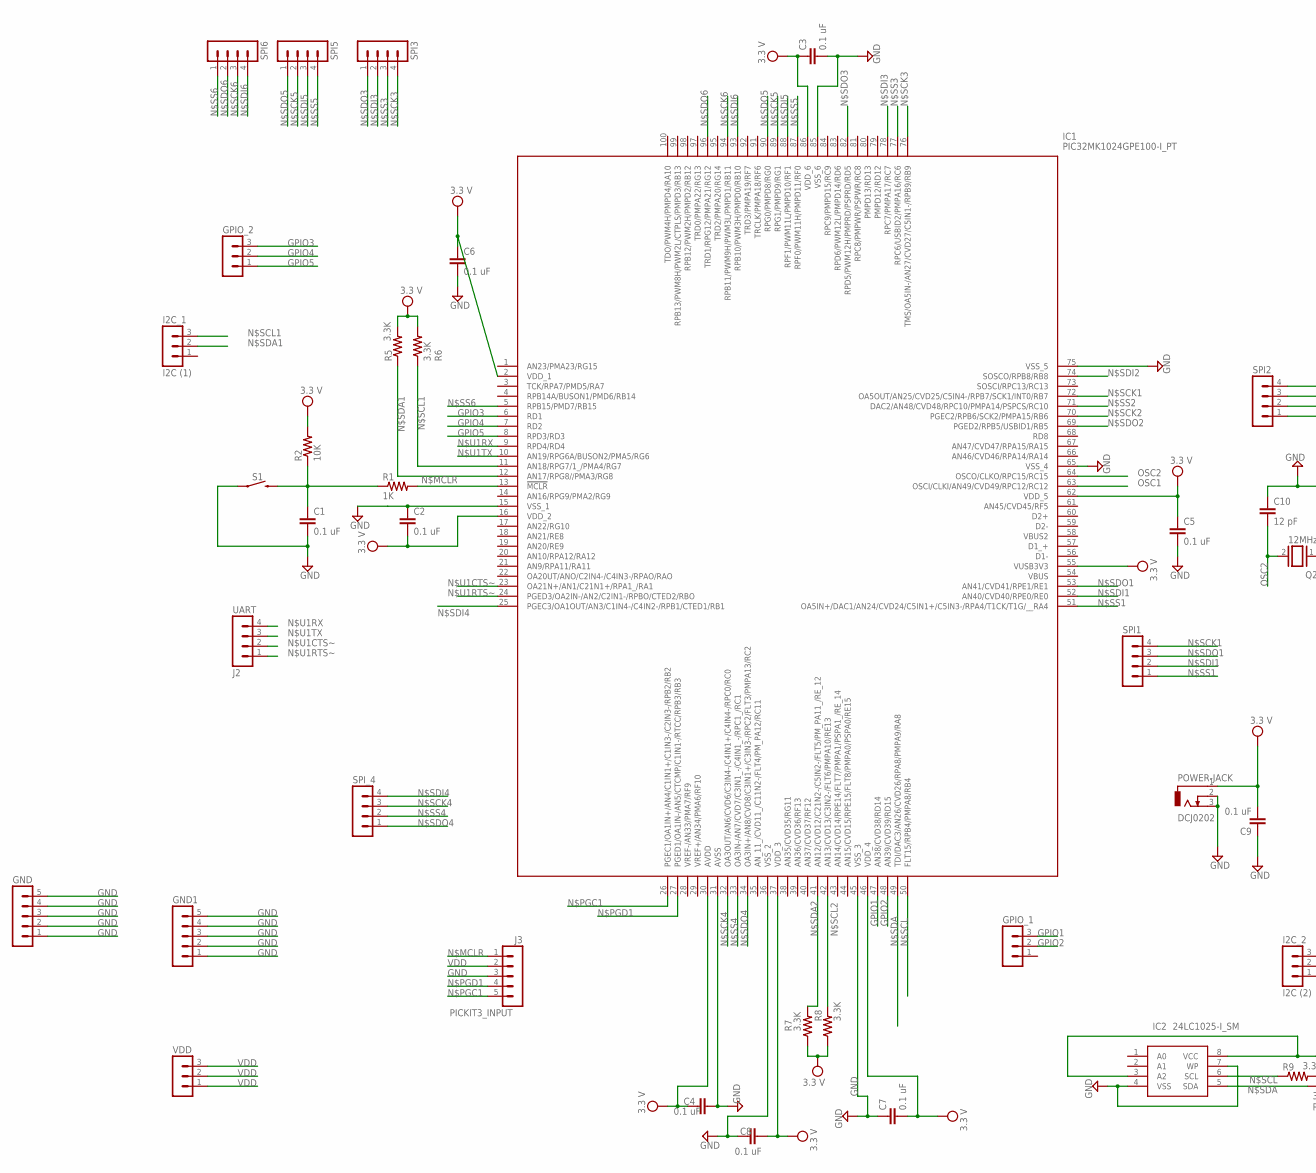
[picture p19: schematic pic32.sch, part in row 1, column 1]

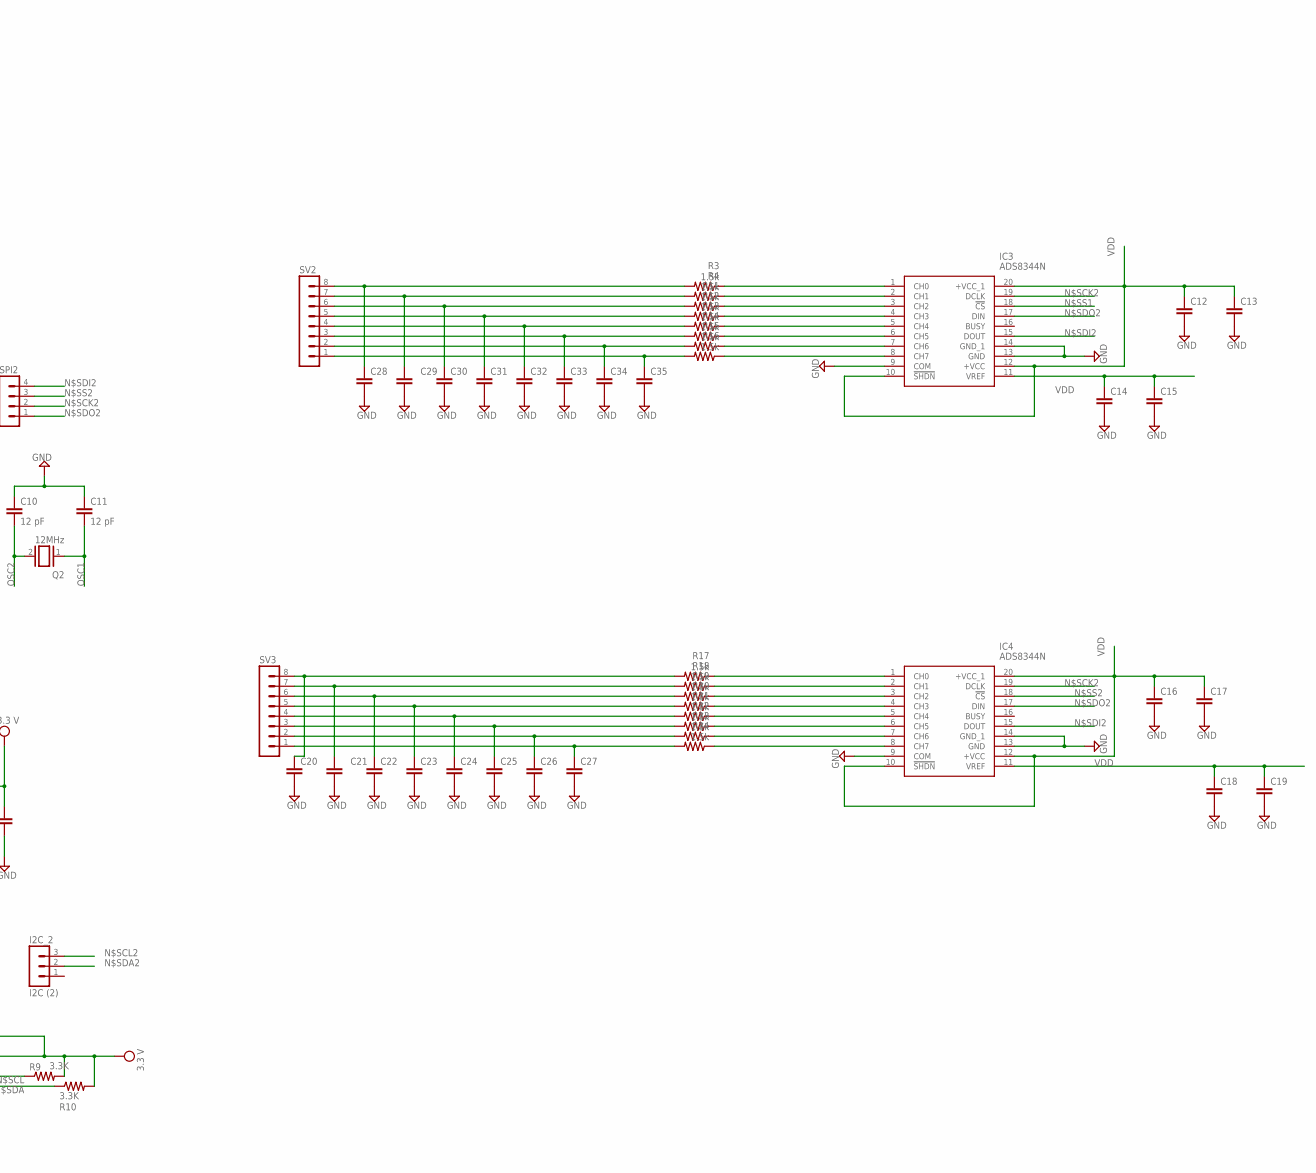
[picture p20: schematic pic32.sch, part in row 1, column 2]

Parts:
C1, C2, C3, C4, C5, C6, C7, C8, C9, C12, C13, C14, C15, C16, C17, C18, C19, C20, C21, C22, C23, C24, C25, C26, C27, C28, C29, C30, C31, C32, C33, C34, C35: 0.1 uF; C025-025X050
C10, C11: 12 pF; C025-025X050
GND, GND1: MA05-1
GPIO_1, GPIO_2: MA03-1
I2C_1: I2C (1); MA03-1
I2C_2: I2C (2); MA03-1
IC1: PIC32MK1024GPE100-I_PT; QFP40P1400X1400X120-100N
IC2: 24LC1025-I_SM; SOIC127P794X203-8N
IC3, IC4: ADS8344N; SOP65P780X200-20N
PICKIT3_INPUT: J3; MA05-1
POWER-JACK: DCJ0202
Q2: 12MHz; QS
R1: 1K; 0207/7
R2: 10K; 0207/7
R3, R4, R11, R12, R13, R14, R15, R16, R17, R18, R19, R20, R21, R22, R23, R24: 1.5k; 0207/7
R5, R6, R7, R8, R9, R10: 3.3K; 0207/7
S1: MOMENTARY-SWITCH-SPST-SMD-6.2MM-TALL; TACTILE_SWITCH_SMD_6.2MM_TALL
SPI1, SPI2, SPI3, SPI5, SPI6: MA04-1
SPI_4: MA04-1
SV2, SV3: MA08-1
UART: J2; MA04-1
VDD: MA03-1

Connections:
GND: C1.2, C2.1, C3.2, C4.1, C5.2, C6.2, C7.1, C8.1, C9.1, C10.1, C11.1, C12.2, C13.2, C14.2, C15.2, C16.2, C17.2, C18.2, C19.2, C20.2, C21.2, C22.2, C23.2, C24.2, C25.2, C26.2, C27.2, C28.2, C29.2, C30.2, C31.2, C32.2, C33.2, C34.2, C35.2, GND.1, GND.2, GND.3, GND.4, GND.5, GND1.1, GND1.2, GND1.3, GND1.4, GND1.5, IC1.15 (VSS_1), IC1.31 (AVSS), IC1.36 (VSS_2), IC1.45 (VSS_3), IC1.65 (VSS_4), IC1.75 (VSS_5), IC1.85 (VSS_6), IC2.4 (VSS), IC2.7 (WP), IC3.9 (COM), IC3.13 (GND), IC3.14 (GND_1), IC4.9 (COM), IC4.13 (GND), IC4.14 (GND_1), PICKIT3_INPUT.3, POWER-JACK.2, POWER-JACK.3, S1.A2 (1)
GPIO1: GPIO_1.3, IC1.47 (AN38/CVD38/RD14)
GPIO2: GPIO_1.2, IC1.48 (AN39/CVD39/RD15)
GPIO3: GPIO_2.3, IC1.6 (RD1)
GPIO4: GPIO_2.2, IC1.7 (RD2)
GPIO5: GPIO_2.1, IC1.8 (RPD3/RD3)
unnamed: C1.1, R1.1, R2.1, S1.B2 (2)
unnamed: C28.1, R3.2, SV2.8
unnamed: IC3.1 (CH0), R3.1
unnamed: IC3.2 (CH1), R4.1
unnamed: IC3.3 (CH2), R11.1
unnamed: IC3.4 (CH3), R12.1
unnamed: IC3.5 (CH4), R13.1
unnamed: IC3.6 (CH5), R14.1
unnamed: IC3.7 (CH6), R15.1
unnamed: IC3.8 (CH7), R16.1
unnamed: IC4.1 (CH0), R17.1
unnamed: C29.1, R4.2, SV2.7
unnamed: C30.1, R11.2, SV2.6
unnamed: C31.1, R12.2, SV2.5
unnamed: C32.1, R13.2, SV2.4
unnamed: C33.1, R14.2, SV2.3
unnamed: C34.1, R15.2, SV2.2
unnamed: C35.1, R16.2, SV2.1
unnamed: IC4.2 (CH1), R18.1
unnamed: IC4.3 (CH2), R19.1
unnamed: IC4.4 (CH3), R20.1
unnamed: C20.1, R17.2, SV3.8
unnamed: C21.1, R18.2, SV3.7
unnamed: C22.1, R19.2, SV3.6
unnamed: C23.1, R20.2, SV3.5
unnamed: C24.1, R21.2, SV3.4
unnamed: C25.1, R22.2, SV3.3
unnamed: C26.1, R23.2, SV3.2
unnamed: C27.1, R24.2, SV3.1
unnamed: IC4.5 (CH4), R21.1
unnamed: IC4.6 (CH5), R22.1
unnamed: IC4.7 (CH6), R23.1
unnamed: IC4.8 (CH7), R24.1
N$MCLR: IC1.13 (!MCLR), PICKIT3_INPUT.1, R1.2
N$PGC1: IC1.26 (PGEC1/OA1IN+/AN4/C1IN1+/C1IN3-/C2IN3-/R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), PICKIT3_INPUT.5
N$PGD1: IC1.27 (PGED1/OA1IN-/AN5/CTCMP/C1IN1-/RTCC/RPB3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), PICKIT3_INPUT.4
N$SCK1: IC1.72 (OA5OUT/AN25/CVD25/C5IN4-/RPB7/SCK1/INT0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), SPI1.4
N$SCK2: IC1.70 (PGEC2/RPB6/SCK2/PMPA15/RB6), IC3.19 (DCLK), IC4.19 (DCLK), SPI2.2
N$SCK3: IC1.76 (TMS/OA5IN-/AN27/CVD27/C5IN1-/RPB9/RB9), SPI3.4
N$SCK4: IC1.32 (OA3OUT/AN6/CVD6/C3IN4-/C4IN1+/C4IN4-/RP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), SPI_4.3
N$SCK5: IC1.89 (RPG1/PMPD9/RG1), SPI5.2
N$SCK6: IC1.94 (RPB11/PWM9H/PWM3L/PMPD1/RB11), SPI6.3
N$SCL: IC1.50 (FLT15/RPB4/PMPA8/RB4), IC2.6 (SCL), R9.1
N$SCL1: I2C_1.3, IC1.11 (AN18/RPG7/1_/PMA4/RG7), R6.1
N$SCL2: I2C_2.3, IC1.42 (AN13/CVD13/C3IN2-/FLT6/PMPA10/RE13), R8.2
N$SDA: IC1.49 (TDI/DAC3/AN26/CVD26/RPA8/PMPA9/RA8), IC2.5 (SDA), R10.1
N$SDA1: I2C_1.2, IC1.12 (AN17/RPG8//PMA3/RG8), R5.1
N$SDA2: I2C_2.2, IC1.41 (AN12/CVD12/C21N2-/C5IN2-/FLT5/PM_PA11_/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), R7.2
N$SDI1: IC1.52 (AN40/CVD40/RPE0/RE0), SPI1.2
N$SDI2: IC1.74 (SOSCO/RPB8/RB8), IC3.15 (DOUT), IC4.15 (DOUT), SPI2.4
N$SDI3: IC1.78 (RPC7/PMPA17/RC7), SPI3.2
N$SDI4: IC1.25 (PGEC3/OA1OUT/AN3/C1IN4-/C4IN2-/RPB1/CTE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), SPI_4.4
N$SDI5: IC1.88 (RPF1/PWM11L/PMPD10/RF1), SPI5.3
N$SDI6: IC1.93 (RPB10/PWM3H/PMPD0/RB10), SPI6.4
N$SDO1: IC1.53 (AN41/CVD41/RPE1/RE1), SPI1.3
N$SDO2: IC1.69 (PGED2/RPB5/USBID1/RB5), IC3.17 (DIN), IC4.17 (DIN), SPI2.1
N$SDO3: IC1.82 (RPD5/PWM12H/PMPRD/PSPRD/RD5), SPI3.1
N$SDO4: IC1.34 (OA3IN+/AN8/CVD8/C3IN1+/C3IN3-/RPC2/FLT3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), SPI_4.1
N$SDO5: IC1.90 (RPG0/PMPD8/RG0), SPI5.1
N$SDO6: IC1.96 (TRD1/RPG12/PMPA21/RG12), SPI6.2
N$SS1: IC1.51 (OA5IN+/DAC1/AN24/CVD24/C5IN1+/C5IN3-/RP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), IC3.18 (!CS), SPI1.1
N$SS2: IC1.71 (DAC2/AN48/CVD48/RPC10/PMPA14/PSPCS/RC10), IC4.18 (!CS), SPI2.3
N$SS3: IC1.77 (RPC6/USBID2/PMPA16/RC6), SPI3.3
N$SS4: IC1.33 (OA3IN-/AN7/CVD7/C3IN1_-/C4IN1_-/RPC1_/R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), SPI_4.2
N$SS5: IC1.87 (RPF0/PWM11H/PMPD11/RF0), SPI5.4
N$SS6: IC1.5 (RPB15/PMD7/RB15), SPI6.1
N$U1CTS~: IC1.23 (OA21N+/AN1/C21N1+/RPA1_/RA1), UART.2
N$U1RTS~: IC1.24 (PGED3/OA2IN-/AN2/C2IN1-/RPBO/CTED2/RBO), UART.1
N$U1RX: IC1.9 (RPD4/RD4), UART.4
N$U1TX: IC1.10 (AN19/RPG6A/BUSON2/PMA5/RG6), UART.3
OSC1: C11.2, IC1.63 (OSCI/CLKI/AN49/CVD49/RPC12/RC12), Q2.1
OSC2: C10.2, IC1.64 (OSCO/CLKO/RPC15/RC15), Q2.2
VDD: C2.2, C3.1, C4.2, C5.1, C6.1, C7.2, C8.2, C9.2, C12.1, C13.1, C14.1, C15.1, C16.1, C17.1, C18.1, C19.1, IC1.2 (VDD_1), IC1.16 (VDD_2), IC1.30 (AVDD), IC1.37 (VDD_3), IC1.46 (VDD_4), IC1.55 (VUSB3V3), IC1.62 (VDD_5), IC1.86 (VDD_6), IC2.3 (A2), IC2.8 (VCC), IC3.10 (!SHDN), IC3.11 (VREF), IC3.12 (+VCC), IC3.20 (+VCC_1), IC4.10 (!SHDN), IC4.11 (VREF), IC4.12 (+VCC), IC4.20 (+VCC_1), PICKIT3_INPUT.2, POWER-JACK.1, R2.2, R5.2, R6.2, R7.1, R8.1, R9.2, R10.2, VDD.1, VDD.2, VDD.3

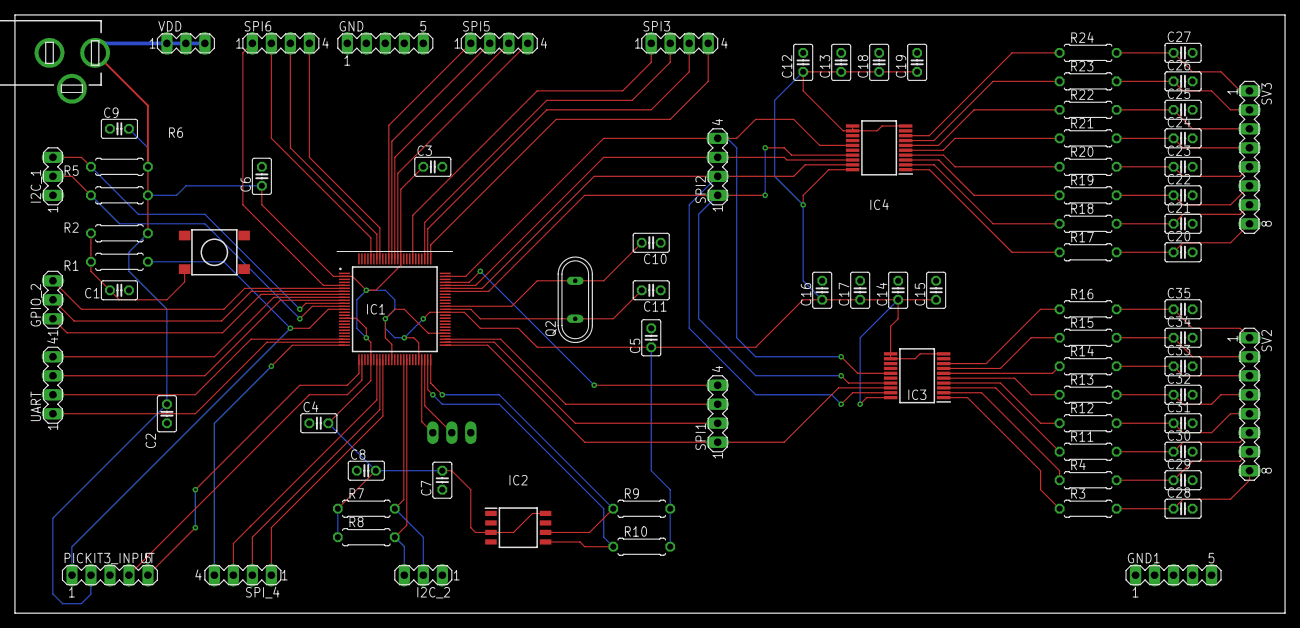
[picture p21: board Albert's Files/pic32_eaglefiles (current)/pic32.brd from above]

Board: 2 copper layers, 169.8 x 80.0 mm, 83 parts (1 on the bottom side), 79 nets.

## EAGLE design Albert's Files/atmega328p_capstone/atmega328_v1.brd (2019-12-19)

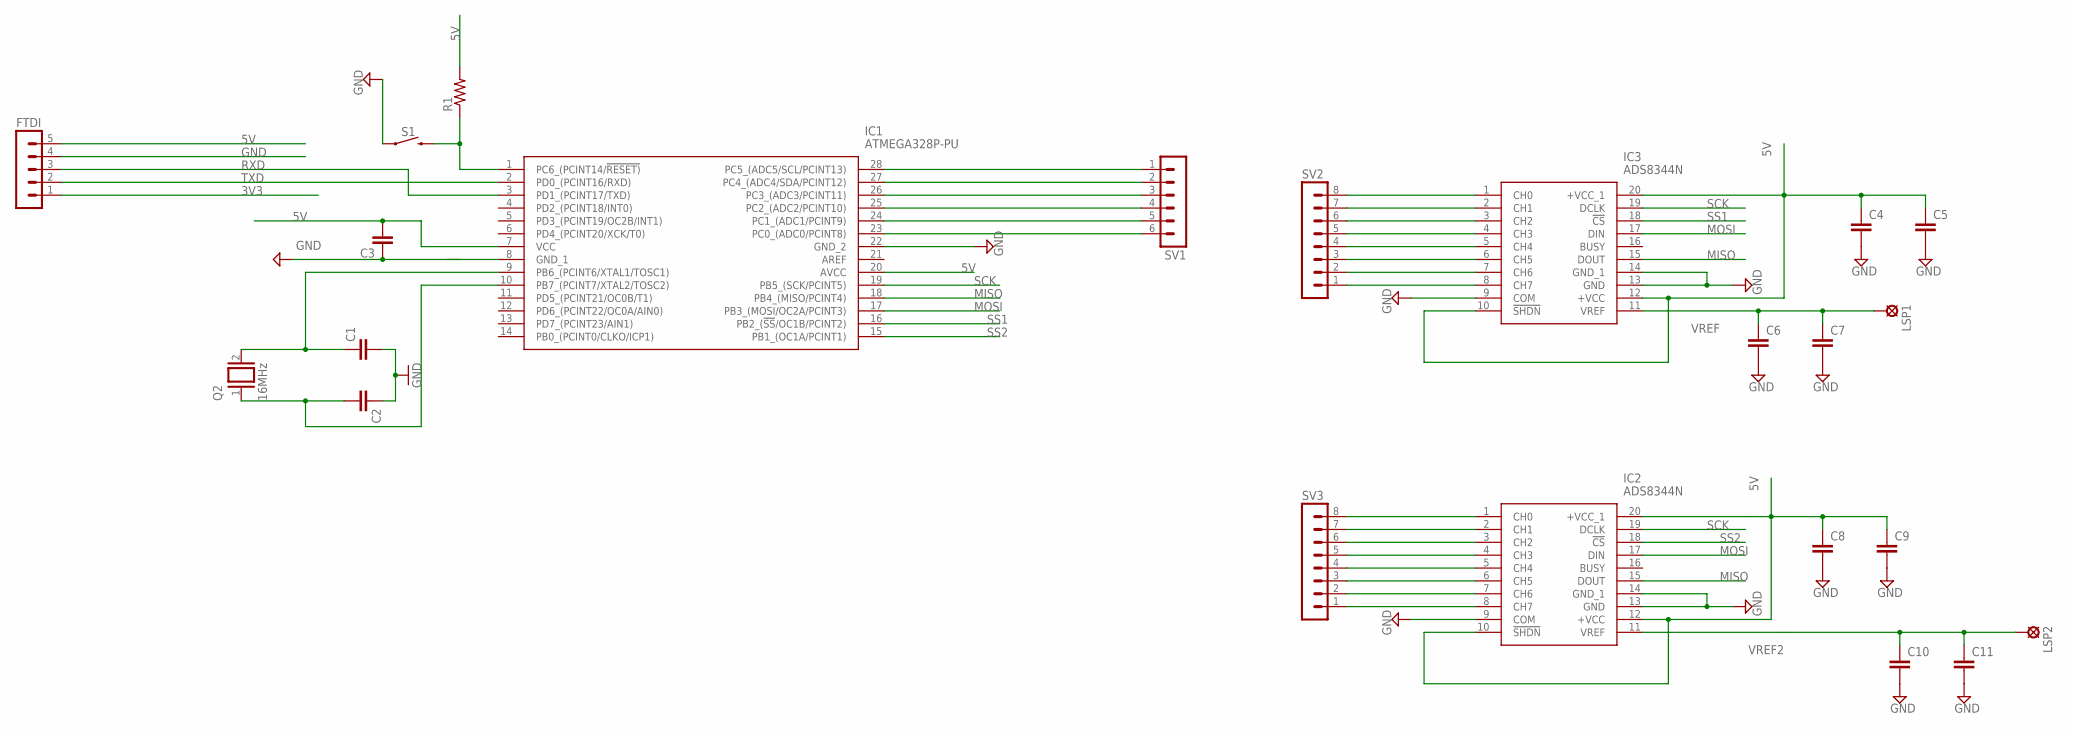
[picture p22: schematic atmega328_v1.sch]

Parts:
C1, C2, C3: C-EU025-050X050; C025-050X050
C4, C5, C6, C7, C8, C9, C10, C11: C-EU050-055X075; C050-055X075
FTDI: MA05-1
IC1: ATMEGA328P-PU; DIP794W53P254L3467H457Q28N
IC2, IC3: ADS8344N; SOP65P780X200-20N
LSP1, LSP2: SE11
Q2: 16MHz; QS
R1: R-US_0309/12; 0309/12
S1: MOMENTARY-SWITCH-SPST-SMD-5.2-REDUNDANT; TACTILE_SWITCH_SMD_5.2MM
SV1: MA06-1
SV2, SV3: MA08-1

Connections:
3V3: FTDI.1
5V: C3.2, C4.1, C5.1, C8.1, C9.1, FTDI.5, IC1.7 (VCC), IC1.20 (AVCC), IC2.10 (!SHDN), IC2.12 (+VCC), IC2.20 (+VCC_1), IC3.10 (!SHDN), IC3.12 (+VCC), IC3.20 (+VCC_1), R1.2
GND: C1.2, C2.1, C3.1, C4.2, C5.2, C6.2, C7.2, C8.2, C9.2, C10.2, C11.2, FTDI.4, IC1.22 (GND_2), IC2.9 (COM), IC2.13 (GND), IC2.14 (GND_1), IC3.9 (COM), IC3.13 (GND), IC3.14 (GND_1), S1.1, S1.2 (1)
MISO: IC1.18 (PB4_(MISO/PCINT4)), IC2.15 (DOUT), IC3.15 (DOUT)
MOSI: IC1.17 (PB3_(MOSI/OC2A/PCINT3)), IC2.17 (DIN), IC3.17 (DIN)
unnamed: IC3.1 (CH0), SV2.8
unnamed: IC1.28 (PC5_(ADC5/SCL/PCINT13)), SV1.1
unnamed: IC1.27 (PC4_(ADC4/SDA/PCINT12)), SV1.2
unnamed: C1.1, IC1.9 (PB6_(PCINT6/XTAL1/TOSC1)), Q2.2
unnamed: C2.2, IC1.10 (PB7_(PCINT7/XTAL2/TOSC2)), Q2.1
unnamed: IC1.26 (PC3_(ADC3/PCINT11)), SV1.3
unnamed: IC1.25 (PC2_(ADC2/PCINT10)), SV1.4
unnamed: IC1.24 (PC1_(ADC1/PCINT9)), SV1.5
unnamed: IC1.23 (PC0_(ADC0/PCINT8)), SV1.6
unnamed: IC1.1 (PC6_(PCINT14/!RESET)), R1.1, S1.3 (2), S1.4 (2)
unnamed: IC3.2 (CH1), SV2.7
unnamed: IC3.3 (CH2), SV2.6
unnamed: IC3.4 (CH3), SV2.5
unnamed: IC3.5 (CH4), SV2.4
unnamed: IC3.6 (CH5), SV2.3
unnamed: IC3.7 (CH6), SV2.2
unnamed: IC3.8 (CH7), SV2.1
unnamed: IC2.1 (CH0), SV3.8
unnamed: IC2.2 (CH1), SV3.7
unnamed: IC2.3 (CH2), SV3.6
unnamed: IC2.4 (CH3), SV3.5
unnamed: IC2.5 (CH4), SV3.4
unnamed: IC2.6 (CH5), SV3.3
unnamed: IC2.7 (CH6), SV3.2
unnamed: IC2.8 (CH7), SV3.1
RXD: FTDI.3, IC1.3 (PD1_(PCINT17/TXD))
SCK: IC1.19 (PB5_(SCK/PCINT5)), IC2.19 (DCLK), IC3.19 (DCLK)
SS1: IC1.16 (PB2_(!SS!/OC1B/PCINT2)), IC3.18 (!CS)
SS2: IC1.15 (PB1_(OC1A/PCINT1)), IC2.18 (!CS)
TXD: FTDI.2, IC1.2 (PD0_(PCINT16/RXD))
VREF: C6.1, C7.1, IC3.11 (VREF), LSP1.MP
VREF2: C10.1, C11.1, IC2.11 (VREF), LSP2.MP

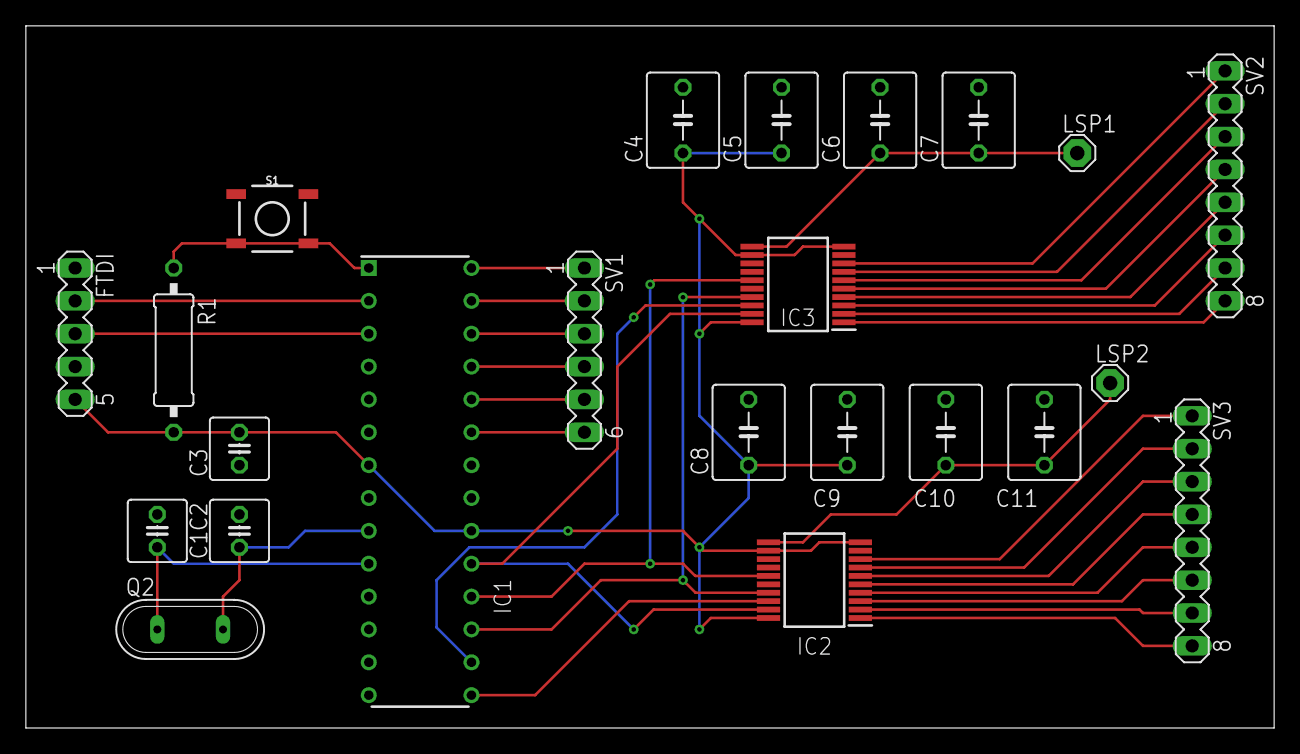
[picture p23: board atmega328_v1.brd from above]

Board: 2 copper layers, 96.5 x 54.3 mm, 23 parts (0 on the bottom side), 36 nets.

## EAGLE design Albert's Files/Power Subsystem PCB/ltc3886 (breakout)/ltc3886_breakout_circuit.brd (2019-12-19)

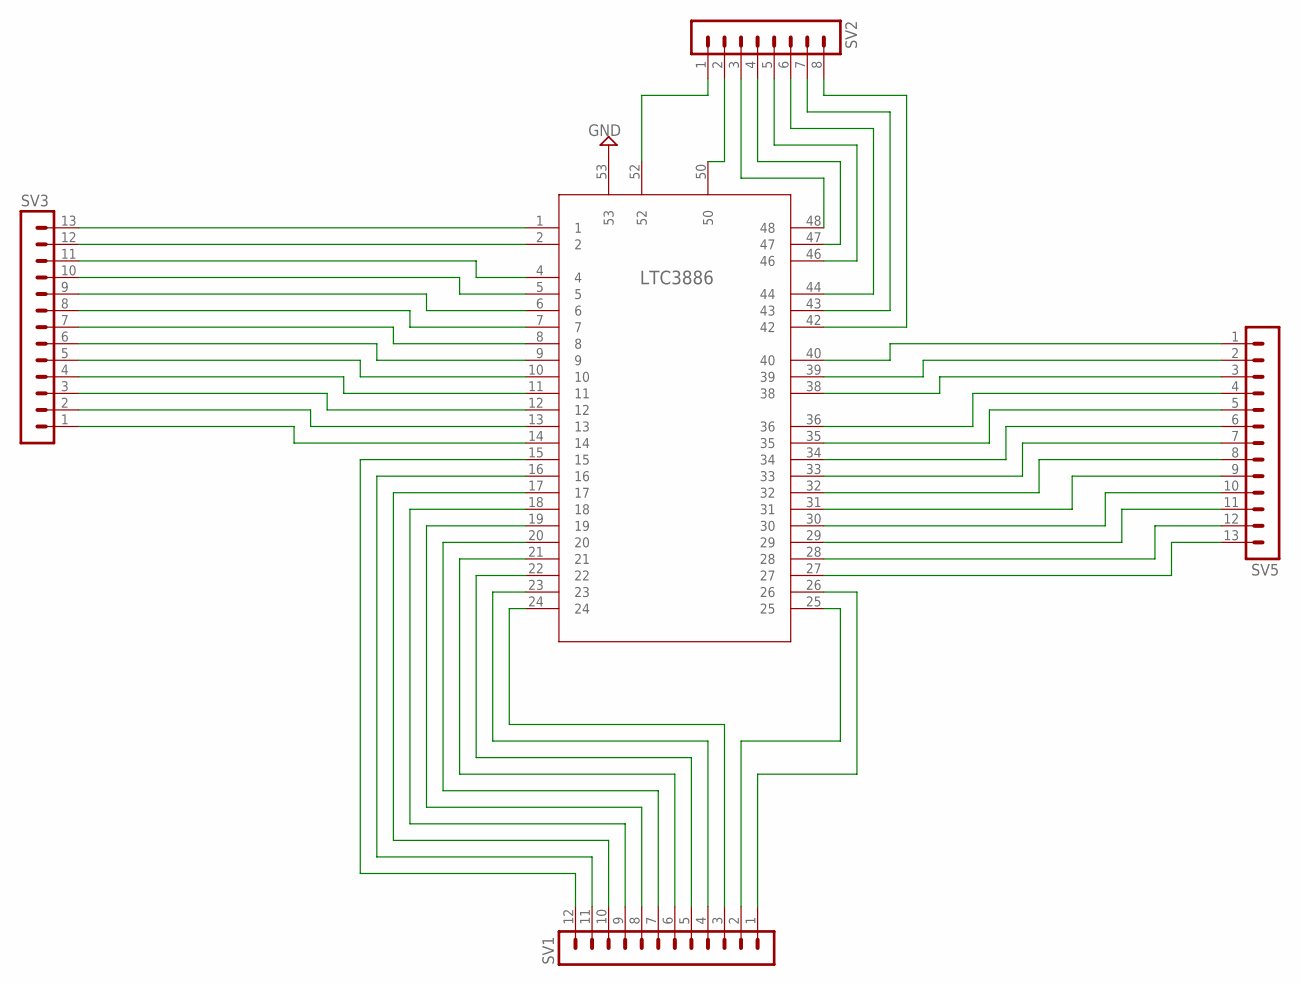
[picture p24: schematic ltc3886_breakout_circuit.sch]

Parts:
SV1: MA12-1
SV2: MA08-1
SV3, SV5: MA13-1
U$1: LTC3886; QFN-52_UKG_2

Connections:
GND: U$1.53
unnamed: SV3.13, U$1.1
unnamed: SV3.12, U$1.2
unnamed: SV3.11, U$1.4
unnamed: SV3.10, U$1.5
unnamed: SV3.9, U$1.6
unnamed: SV3.8, U$1.7
unnamed: SV3.7, U$1.8
unnamed: SV3.6, U$1.9
unnamed: SV3.5, U$1.10
unnamed: SV3.4, U$1.11
unnamed: SV3.3, U$1.12
unnamed: SV3.2, U$1.13
unnamed: SV3.1, U$1.14
unnamed: SV1.12, U$1.15
unnamed: SV1.11, U$1.16
unnamed: SV1.10, U$1.17
unnamed: SV1.9, U$1.18
unnamed: SV1.8, U$1.19
unnamed: SV1.7, U$1.20
unnamed: SV1.6, U$1.21
unnamed: SV2.3, U$1.48
unnamed: SV2.4, U$1.47
unnamed: SV2.5, U$1.46
unnamed: SV2.6, U$1.44
unnamed: SV2.7, U$1.43
unnamed: SV2.8, U$1.42
unnamed: SV5.1, U$1.40
unnamed: SV5.2, U$1.39
unnamed: SV5.3, U$1.38
unnamed: SV5.4, U$1.36
unnamed: SV5.5, U$1.35
unnamed: SV5.6, U$1.34
unnamed: SV5.7, U$1.33
unnamed: SV5.8, U$1.32
unnamed: SV5.9, U$1.31
unnamed: SV5.10, U$1.30
unnamed: SV5.11, U$1.29
unnamed: SV5.12, U$1.28
unnamed: SV5.13, U$1.27
unnamed: SV1.1, U$1.26
unnamed: SV1.5, U$1.22
unnamed: SV1.4, U$1.23
unnamed: SV1.3, U$1.24
unnamed: SV1.2, U$1.25
unnamed: SV2.1, U$1.52
unnamed: SV2.2, U$1.50


Board: 2 copper layers, 123.2 x 86.0 mm, 5 parts (0 on the bottom side), 46 nets.

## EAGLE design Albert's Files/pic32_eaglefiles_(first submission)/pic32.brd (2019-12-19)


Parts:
C1, C2, C3, C4, C5, C6, C7, C8, C9: 0.1 uF; C025-025X050
C10, C11: 12 pF; C025-025X050
IC1: PIC32MK1024GPE100-I_PT; QFP40P1400X1400X120-100N
IC2: 24LC1025-I_SM; SOIC127P794X203-8N
PICKIT3_INPUT: J3; MA05-1
POWER_JACK: DCJ0202
Q2: 12MHz; QS
R1: 1K; 0207/7
R2: 10K; 0207/7
R3, R4, R5, R6, R9, R10: 3.3K; 0207/7
SPI_INTERFACE: J1; MA09-1
SV1: GPIO; MA06-1
SV2: I2C (1); MA03-1
SV3: I2C (2); MA03-1
UART: J2; MA04-1

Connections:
GND: C1.2, C2.1, C3.2, C4.1, C5.2, C6.2, C7.1, C8.1, C9.1, C10.1, C11.1, IC1.15 (VSS_1), IC1.31 (AVSS), IC1.36 (VSS_2), IC1.45 (VSS_3), IC1.65 (VSS_4), IC1.75 (VSS_5), IC1.85 (VSS_6), IC2.4 (VSS), IC2.7 (WP), PICKIT3_INPUT.3, POWER_JACK.2, POWER_JACK.3, UART.1
unnamed: C1.1, R1.1, R2.1
N$GPIO1: IC1.39 (AN36/CVD36/RF13), SV1.6
N$GPIO2: IC1.40 (AN37/CVD37/RF12), SV1.5
N$GPIO3: IC1.41 (AN12/CVD12/C21N2-/C5IN2-/FLT5/PM_PA11_/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), SV1.4
N$GPIO4: IC1.42 (AN13/CVD13/C3IN2-/FLT6/PMPA10/RE13), SV1.3
N$GPIO5: IC1.43 (AN14/CVD14/RPE14/FLT7/PMPA1/PSPA1_/RE_14), SV1.2
N$GPIO6: IC1.44 (AN15/CVD15/RPE15/FLT8/PMPA0/PSPA0/RE15), SV1.1
N$MCLR: IC1.13 (!MCLR), PICKIT3_INPUT.1, R1.2
N$MISO: IC1.78 (RPC7/PMPA17/RC7), SPI_INTERFACE.3
N$MOSI: IC1.77 (RPC6/USBID2/PMPA16/RC6), SPI_INTERFACE.2
N$PGC1: IC1.26 (PGEC1/OA1IN+/AN4/C1IN1+/C1IN3-/C2IN3-/R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), PICKIT3_INPUT.5
N$PGD1: IC1.27 (PGED1/OA1IN-/AN5/CTCMP/C1IN1-/RTCC/RPB3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), PICKIT3_INPUT.4
N$SCK: IC1.72 (OA5OUT/AN25/CVD25/C5IN4-/RPB7/SCK1/INT0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), SPI_INTERFACE.1
N$SCL: IC1.70 (PGEC2/RPB6/SCK2/PMPA15/RB6), IC2.6 (SCL), R9.1
N$SCL1: IC1.11 (AN18/RPG7/1_/PMA4/RG7), R6.1, SV2.3
N$SCL2: IC1.49 (TDI/DAC3/AN26/CVD26/RPA8/PMPA9/RA8), R4.1, SV3.3
N$SDA: IC1.69 (PGED2/RPB5/USBID1/RB5), IC2.5 (SDA), R10.1
N$SDA1: IC1.12 (AN17/RPG8//PMA3/RG8), R5.1, SV2.2
N$SDA2: IC1.50 (FLT15/RPB4/PMPA8/RB4), R3.1, SV3.2
N$SS1: IC1.81 (RPC8/PMPWR/PSPWR/RC8), SPI_INTERFACE.4
N$SS2: IC1.87 (RPF0/PWM11H/PMPD11/RF0), SPI_INTERFACE.5
N$SS3: IC1.88 (RPF1/PWM11L/PMPD10/RF1), SPI_INTERFACE.6
N$SS4: IC1.89 (RPG1/PMPD9/RG1), SPI_INTERFACE.7
N$SS5: IC1.90 (RPG0/PMPD8/RG0), SPI_INTERFACE.8
N$SS6: IC1.93 (RPB10/PWM3H/PMPD0/RB10), SPI_INTERFACE.9
N$U1RX: IC1.22 (OA20UT/ANO/C2IN4-/C4IN3-/RPAO/RAO), UART.3
N$U1TX: IC1.23 (OA21N+/AN1/C21N1+/RPA1_/RA1), UART.2
OSC1: C11.2, IC1.63 (OSCI/CLKI/AN49/CVD49/RPC12/RC12), Q2.1
OSC2: C10.2, IC1.64 (OSCO/CLKO/RPC15/RC15), Q2.2
VDD: C2.2, C3.1, C4.2, C5.1, C6.1, C7.2, C8.2, C9.2, IC1.2 (VDD_1), IC1.16 (VDD_2), IC1.30 (AVDD), IC1.37 (VDD_3), IC1.46 (VDD_4), IC1.55 (VUSB3V3), IC1.62 (VDD_5), IC1.86 (VDD_6), IC2.3 (A2), IC2.8 (VCC), PICKIT3_INPUT.2, POWER_JACK.1, R2.2, R3.2, R4.2, R5.2, R6.2, R9.2, R10.2, UART.4


Board: 2 copper layers, 81.3 x 64.4 mm, 29 parts (0 on the bottom side), 31 nets.

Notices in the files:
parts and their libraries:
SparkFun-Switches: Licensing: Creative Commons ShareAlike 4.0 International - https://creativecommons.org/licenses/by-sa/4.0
